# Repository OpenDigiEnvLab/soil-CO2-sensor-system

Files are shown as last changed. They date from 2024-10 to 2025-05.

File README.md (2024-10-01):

This repository provides supplementary information for the manuscript "**Overcoming barriers in long-term, continuous monitoring of soil CO2 flux: A low-cost sensor system**"
by Thi Thuc Nguyen, Nadav Bekin, Ariel Altman, Martin Maier, Nurit Agam, Elad Levintal

The repository includes:
1. Do-it-yourself guide to replicate CO2 sensor system: "CO2 sensor system DIY guide"
2.  Arduino codes of two versions of the system (Version 1:  CO2O2Soils_withRelay_6CO2sensors.ino and Version 2: CO2O2SoilsTypeB_blues_6CO2Sensors_Teros12_Serial.ino)
3.  STL file "sensor box 3" is for 3D printing frames for SCD30 sensor coating.

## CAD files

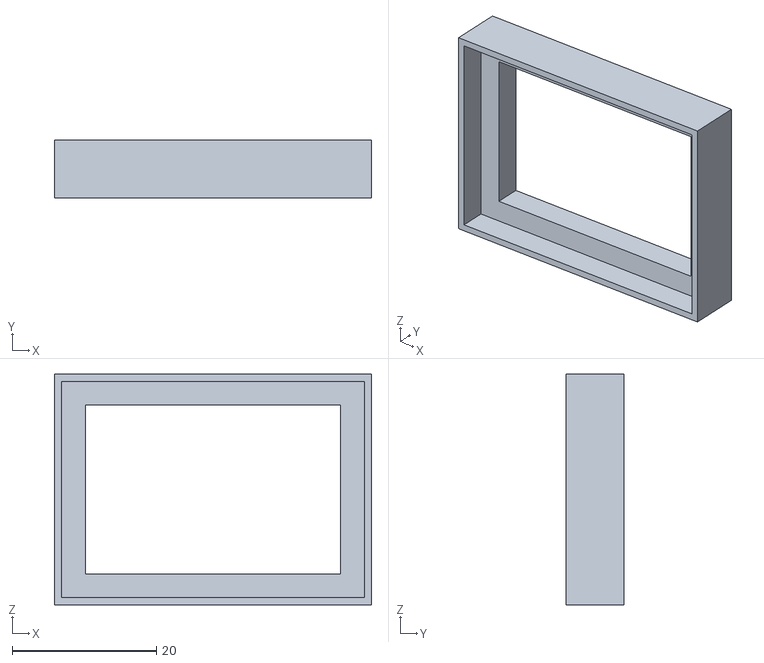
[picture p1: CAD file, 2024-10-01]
sensor box 3.STL
44.0 x 8.00 x 32.0

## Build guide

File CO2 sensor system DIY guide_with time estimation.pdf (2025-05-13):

Overcoming barriers in long-term, continuous monitoring of soil CO2 flux:

A low-cost sensor system

Thi Thuc Nguyen, Nadav Bekin, Ariel Altman, Martin Maier, Nurit Agam, Elad Levintal

This is a do-it-yourself guide for building a low-cost sensor system. Each system comprises a control unit and a sensing unit. There are two versions available, with the primary difference being that a modem and a Teros 12 moisture sensor are included in version 2. Arduino codes for both versions are available on our GitHub page.

Version 1: https://github.com/OpenDigiEnvLab/soil--sensor-system/blob/main/O2Soils_withRelay_6sensors.ino (https://github.com/OpenDigiEnvLab/soil--sensor-system/blob/main/O2Soils_withRelay_6sensors.ino)

Version 2: https://github.com/OpenDigiEnvLab/soil--sensor-system/blob/main/O2SoilsTypeB_blues_6Sensors_Teros12_Serial.ino (https://github.com/OpenDigiEnvLab/soil--sensor-system/blob/main/O2SoilsTypeB_blues_6Sensors_Teros12_Serial.ino)

The schematic designs of two versions are illustrated in the picture below:

Version 1:

Version 2:

Protocol

### 1. Control unit

To replicate the control unit of version 1, prepare the components as listed in Table 1, and follow procedure (1).

To replicate the control unit of version 2, prepare the components as listed in Table 2, and follow procedure (2).

### 2. Sensing unit

The procedure to prepare SCD30 sensors and microclimate sensor are same for both versions.

There is only one additional step to Version 2 as Teros 12 moisture sensor is included in the system.

The preparation of the sensing unit mainly involves waterproof shielding of SCD30 sensors for underground soil measurements and wiring SCD30 sensors for the connection to the control unit.

There are two designs of the waterproof shield:

- Thin coating design (TC design): using PTFE membrane and epoxy (or only PTFE membranes)
- 50 ml Falcon tube design (FT design): using a 50 ml Falcon tube.

To replicate the TC design, follow procedure (3).

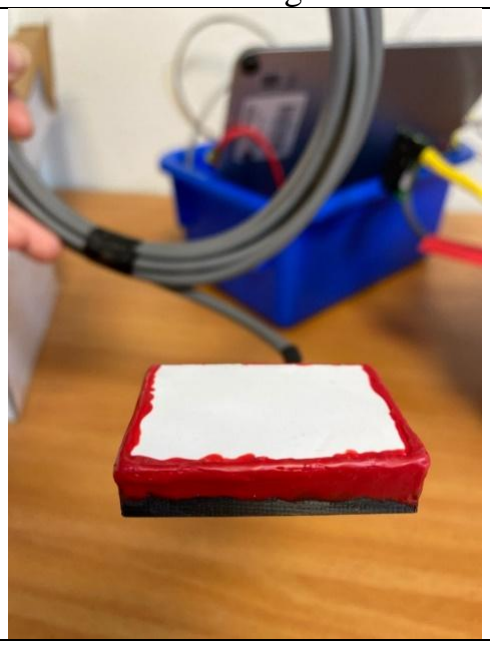
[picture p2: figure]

To replicate the FT design, follow procedure (4).

TC design | FT design

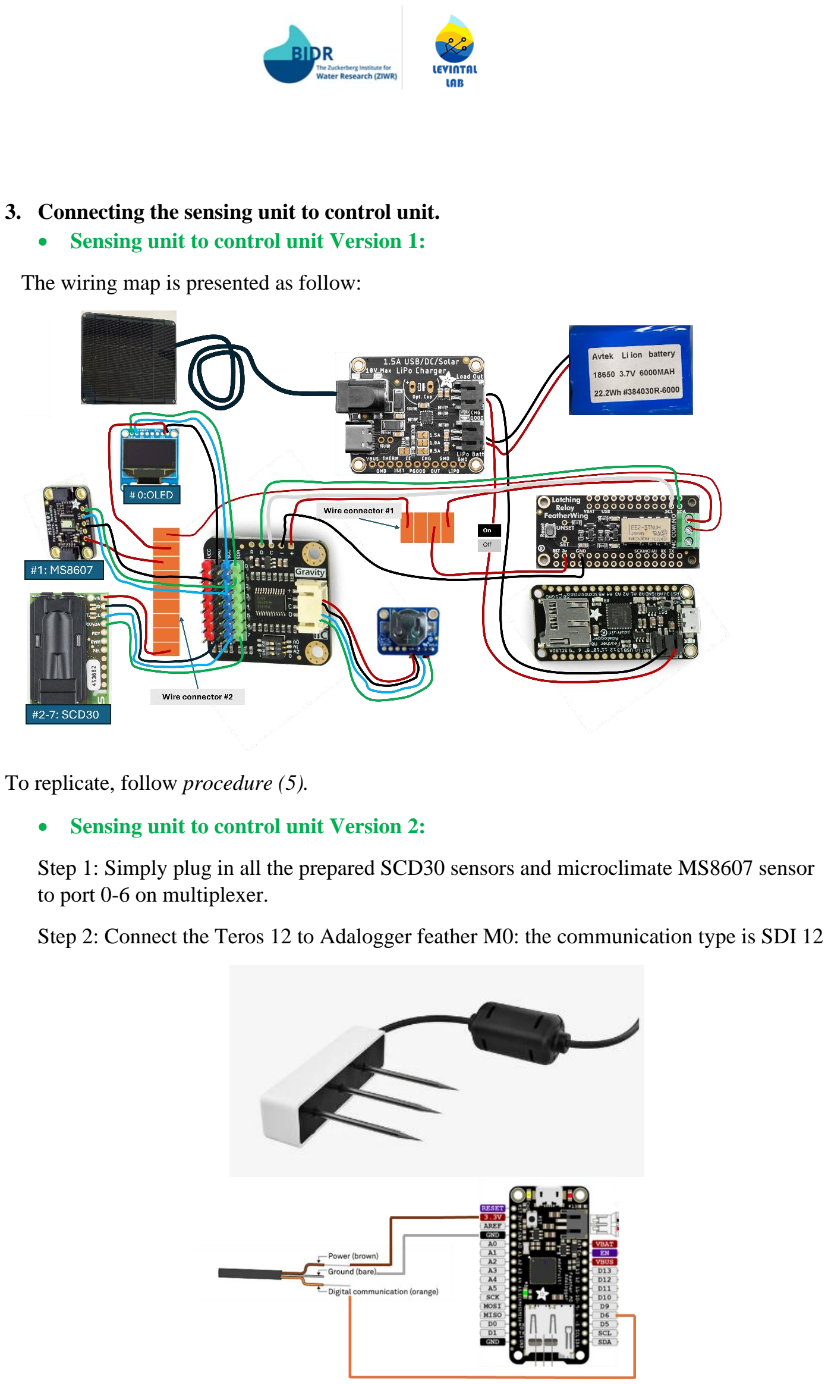
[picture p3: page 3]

3. Connecting the sensing unit to control unit.
- Sensing unit to control unit Version 1:

The wiring map is presented as follow:

To replicate, follow procedure (5).

- Sensing unit to control unit Version 2:
Step 1: Simply plug in all the prepared SCD30 sensors and microclimate MS8607 sensor to port 0-6 on multiplexer.
Step 2: Connect the Teros 12 to Adalogger feather M0: the communication type is SDI 12

4. To upload Arduino code and test sensors, follow procedure (6).

Time estimation table for building one standard system

(1 control unit + 1 sensing unit (4 thin coating sensors, 2 falcon tube sensors, 1 microclimate sensor, 1 moisture sensor))

No | Unit | Procedure | Estimated hours
1 | Control unit | Procedure (1) | ~2-5 hours
| | Procedure (2) | ~2-5 hours
2 | Sensing unit | Procedure (3) | ~24 hours (including epoxy’s drying time)
| | Procedure (4) (2 falcon tube sensors) | ~1 hour/sensor
3 | Connecting the sensing unit to the control unit | Procedure (5) | ~5 hours
4 | Upload Arduino code and test sensors | Procedure (6) | ~ 3-24 hours

Contents

Procedure (5): Connecting the sensor unit to the control unit version 1 and test the system .24

Table 1: Hardware components for system Version 1.

Component | Quantify | Cost (USD)
Sources | Comments

Hardware components for control unit – Version 1

Feather M0 Adalogger | 1 | 19.95 | Adafruit (https://www.adafruit.com/product/2796)
RTC DS3231 with CR1220 battery | 1 | 17.5 | Adafruit (https://www.adafruit.com/product/3013) | Provides accurate time for the data logger; can be purchased from other suppliers
Gravity 1-to-8 I2C Multiplexer | 1 | 6.9 | DFRobot (https://www.dfrobot.com/product-1780.html) | Enables the connections of multiple /O2 sensors to one data logger; Can be purchased from other suppliers
0.96" 128x64 OLED Graphic Display | 1 | 17.5 | Adafruit (https://www.adafruit.com/product/326) | Can be purchased from other suppliers
Latching relay FeatherWing | 1 | 7.95 | Adafruit (https://www.adafruit.com/product/2923) | For power control: programmed to turn on and turn off the system when needed
P2886A feather header kit | 1 | 0.95 | Adafruit (https://www.adafruit.com/product/2886) | To connect Feather M0 Adalogger with Latching relay FeatherWing
3.6V 6000 mAh battery | 1 | 50 | Local suppliers or online (e.g., Amazon) | To provide power for the control and sensor unit
Adafruit Universal USB / DC / Solar Lithium Ion/Polymer charger - bq24074 | 1 | 14.95 | Adafruit (https://www.adafruit.com/product/4755) | To charge the battery using the solar energy from solar panel
Medium 6V 2W Solar panel | 1 | 29 | Adafruit (https://www.adafruit.com/product/200)
SD/MicroSD memory card (8GB SDHC) | | 9.95 | Adafruit (https://www.adafruit.com/product/1294) | Can be purchased from other suppliers

Hardware components for sensing unit – Version 1 + 2

SCD30 sensor (0-10,000ppm, I2C) | 6 | 6 ×61.79 | Digikey (https://www.digikey.com/en/products/detail/sensirion-ag/SCD30/8445334) | + 4 sensors with thin coating and 2 sensors with falcon tube + Can be purchased from other suppliers
STEMMA QT MS8607 humidity temperature pressure sensor | 1 | 14.95 | Adafruit (https://www.adafruit.com/product/4716) | To measure atmospheric humidity, temperature, and pressure
50ml Falcon tube (https://www.fishersci.com/shop/products/falcon-50ml-conical-centrifuge-tubes-2/p-193321) | 2 | 1 | Local suppliers or online (e.g., Amazon) | To use for waterproofing SCD30 sensors
PTEE membrane 1/16” x 6” x 6” GR Sheets | 1 | 37.97 | McMaster (https://www.mcmaster.com/ptfe/ultra-chemical-resistant-compressible-ptfe-gasket-material-7/thickness~1-16/) | To use in the waterproofing design, allowing exchange of between sensors and the environment
Cables, wires, and general equipment: + 7 × 4-wire cable 3m (6 for SCD30 sensors and 1 for MS8607 sensor) | | ~30 | Local suppliers or online (e.g., Amazon)

+ Wires in colors white, green, red, black + 8 × 4-pin cables with Female Dupont connectors (https://www.amazon.de/-/en/Pin-Dupont-Cable-Female-Connector/dp/B01B360810) + 3 × JST PH 2pin cable-male connector (https://www.adafruit.com/product/3814) + 1× 4pin PH2.0 cable-male connector (https://www.dfrobot.com/product-2554.html) + 2 lever wire connectors + on/off switch + shrinking sleeves different sizes

Epoxy | 500 grams | 10 | Local suppliers or online (e.g., Amazon) | To use for waterproofing SCD30 sensors
Plasti Dip | 1 bottle | 10 | Local suppliers or online (e.g., Amazon) | To use for waterproofing SCD30 sensors
3D printed frame | 4 | 10 | Locally produced | To print the 3D frame for SCD30 sensor, Upload the sensor box 3.STL file (https://github.com/OpenDigiEnvLab/soil-CO2-sensor-system/blob/main/sensor%20box%203.STL) to a 3D printer and print a frame for each SCD30 sensor. We used Prusa i3 MK3S 3d printer (https://www.prusa3d.com/product/original-prusa-i3-mk3s-3d-printer-3/) using black PETG as the printing material.
Teros 12 | 1 | 450 | METER (https://metergroup.com/products/teros-12/) | Teros 12 is included in Version 2 to measure soil moisture simultaneously.

Table 2: Hardware components for system Version 2.

Component | Quantify | Cost (USD)
Sources | Comments

Hardware components for control unit – Version 2

Feather M0 Adalogger | 1 | 19.95 | Adafruit (https://www.adafruit.com/product/2796)
DS3231 Precision RTC FeatherWing with CR1220 battery | 1 | 13.95 | Adafruit (https://www.adafruit.com/product/3028) | Provides accurate time for the data logger; can be purchased from other suppliers
Notecarrier_F V1.3 | 1 | 25 | Blues (https://shop.blues.com/products/notecarrier-f)
Notecard cellular WB AN500 | 1 | 59 | Blues (https://shop.blues.com/products/notecard)
Gravity 1-to-8 I2C Multiplexer | 1 | 6.9 | DFRobot (https://www.dfrobot.com/product-1780.html) | Enables the connections of multiple /O2 sensors to one data logger; Can be purchased from other suppliers
P2886A feather header kit | 1 | 0.95 | Adafruit (https://www.adafruit.com/product/2886) | To connect Feather M0 Adalogger with RTC FeatherWing
3.6V 6000 mAh battery | 1 | 50 | Local suppliers or online (e.g., Amazon) | To provide power for the control and sensor unit
Medium 6V 2W Solar panel | 1 | 29 | Adafruit (https://www.adafruit.com/product/200)
SD/MicroSD memory card (8GB SDHC) | | 9.95 | Adafruit (https://www.adafruit.com/product/1294) | Can be purchased from other suppliers

Hardware components for sensing unit Version 2 is same as Version 1, with the only difference is the addition of Teros 12 in Version 2 (see Table 1)

## Procedure (1): Control unit Version 1

Step 1: prepare Adalogger.
- Solder the Adalogger to the header 2886 kit.
Step 2: prepare the latching relay Adafruit.

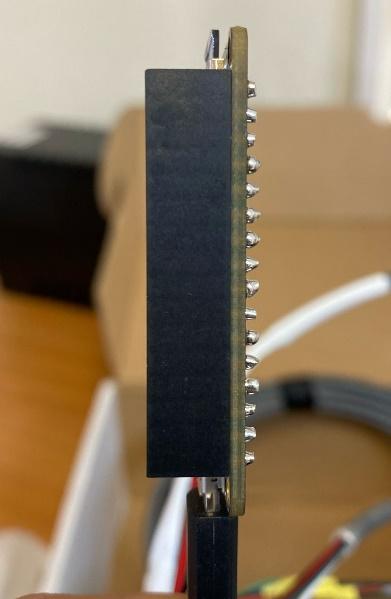
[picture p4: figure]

- The latching relay Adafruit has two pieces, solder 'the small latching piece' (1) to the main part of the relay.
- Solder latching relay Adafruit to male header pins (2). The male header pins and the header 2886 are compatible, creating the communication between the Adalogger and the latching relay Adafruit.

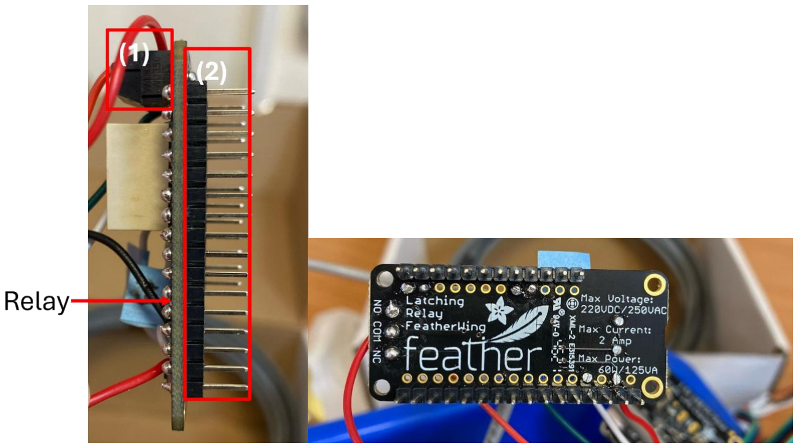
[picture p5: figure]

- Solder 2 wires 3-4 cm long connecting: Port 'set' to port #13
Port 'unset' to port #12
And label them
- Connect 2 red wires 13 cm long to two ports in 'the small latching piece' of the relay.

- Solder 13cm wires in green, white, red, black to following ports: Green wire to SDA port
White wire to SCL port
Red wire to 3V port
Black wire to GND port
These wires will be connected to other parts of the control unit.

The black piece connected
with red wires

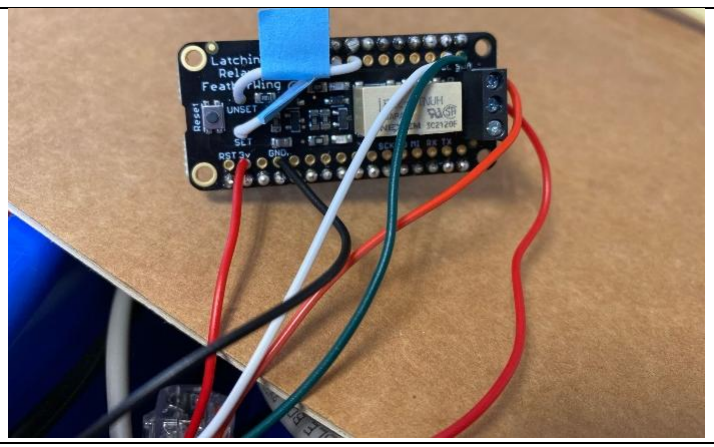
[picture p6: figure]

Latching relay Adafruit after wire soldering

Step 3: preparing the DFR 0576 multiplexer.
- Solder 15cm wires in green, white, red, black to following ports of the multiplexer:
Green wire to SDA port
White wire to SCL port
Red wire to 3V port
Black wire to GND port
Step 4: preparing the real-time clock.
- Solder the DS3231 RTC to a 15cm long 4-pin cable (green, blue, red, black) with a 4pin PH2.0 male header (that compatible to a female port of the multiplexer) Green wire to SDA port

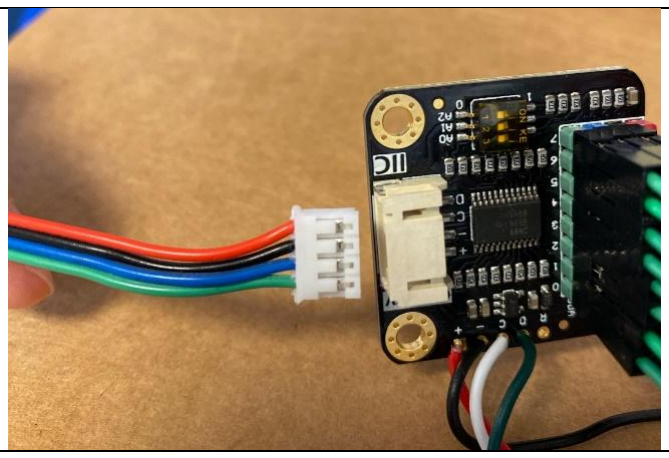
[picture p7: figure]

Blue wire to SCL port
Red wire to 3V port
Black wire to GND port
- Insert CR1220 battery into the RTC.

The DS3231 RTC with battery soldered to a 4pin cable

4pin PH2.0 male header connects the RTC to the multiplex

Step 5: preparing 128x64 OLED (Adafruit 326).
- Solder 13 cm wires in green, white, red, black to the following ports of the OLED: Green wire to data port
White wire to Clk port
Red wire to Vin port
Black wire to GND port
- Solder these wires with wires of a Dupont connector: Green wire to Green wire
White wire to Blue wire
Red wire to Red wire
Black wire to Black wire
- Protect exposed wires with shrinking sleeves.

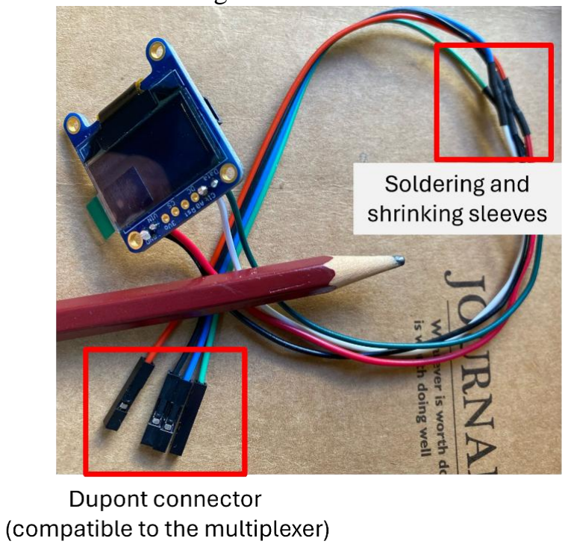
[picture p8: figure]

Step 6: Preparing battery solar panel
- Extend the cable of the solar panel:
Cut the red cable and expose the red and black wires inside.
Solder the red and black wires with red and black wires of an extended cable. *Please note that the solar panel will be outside in the field conditions, use extra shrinking sleeves and tape to protect the soldered connection.

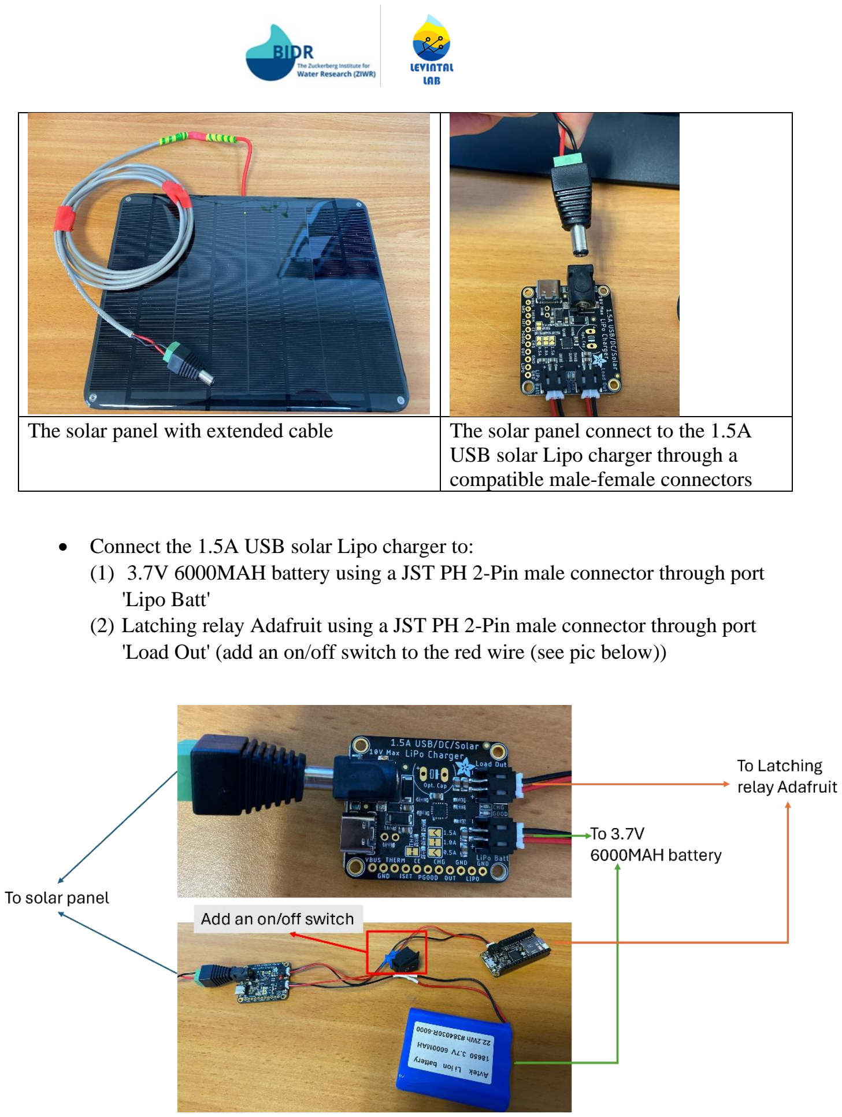
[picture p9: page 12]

The solar panel with extended cable | The solar panel connect to the 1.5A USB solar Lipo charger through a compatible male-female connectors
- Connect the 1.5A USB solar Lipo charger to:
(1) 3.7V 6000MAH battery using a JST PH 2-Pin male connector through port 'Lipo Batt'
(2) Latching relay Adafruit using a JST PH 2-Pin male connector through port 'Load Out' (add an on/off switch to the red wire (see pic below))

## Procedure (2): Control unit Version 2

Step 1: Set up Blues modem by resembling Blues Notecard + Notecarrier + Antenna

For details, please refer to Blues website (https://dev.blues.io/quickstart/notecard-quickstart/notecard-and-notecarrier-f/)

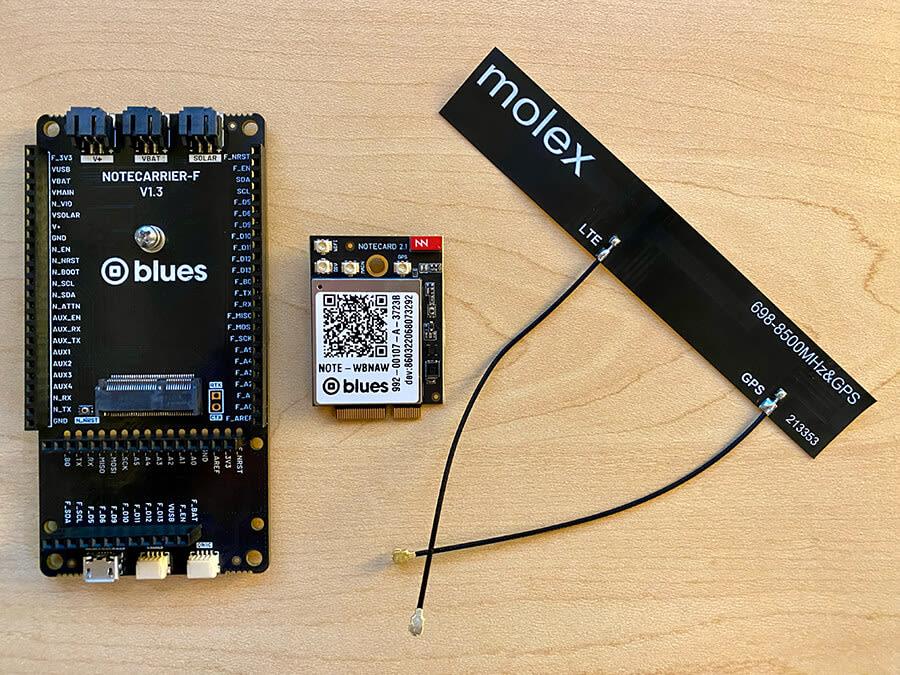
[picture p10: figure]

Step 2: Stack Adafruit feather M0 + RTC FeatherWing + Blues modem
RTC FeatherWing | Adafruit feather M0 | Blues modem

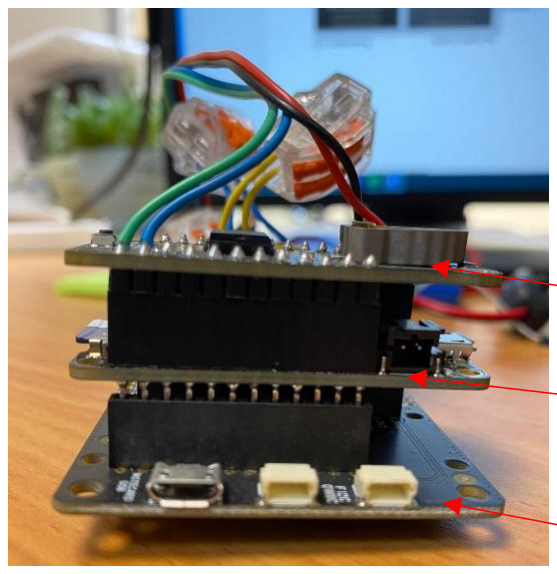
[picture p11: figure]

Soldering is needed to secure the header kit to Adalogger Feather M0 and RTC FeatherWing.

Step 3: Communicate Adalogger + Blues modem

Blues modem

Adalogger

RTC FeatherWing

- The communication between Blues modem and Adalogger can be I2C or Serial (Serial is suitable when there are a lot of sensors with long cables). Only for Serial communication, these following ports need to be connected.

On the Blues notecarrier:

Connect F_TX → N_RX (with F stands for Feather and N stands for Notecard)

Connect F_RX → N_TX

- For power saving, Blues modem can turn Adalogger on and off at desired interval. For this function, connect F_EN → ATTN
- Put switches at the back of the Notecarrier as follows:

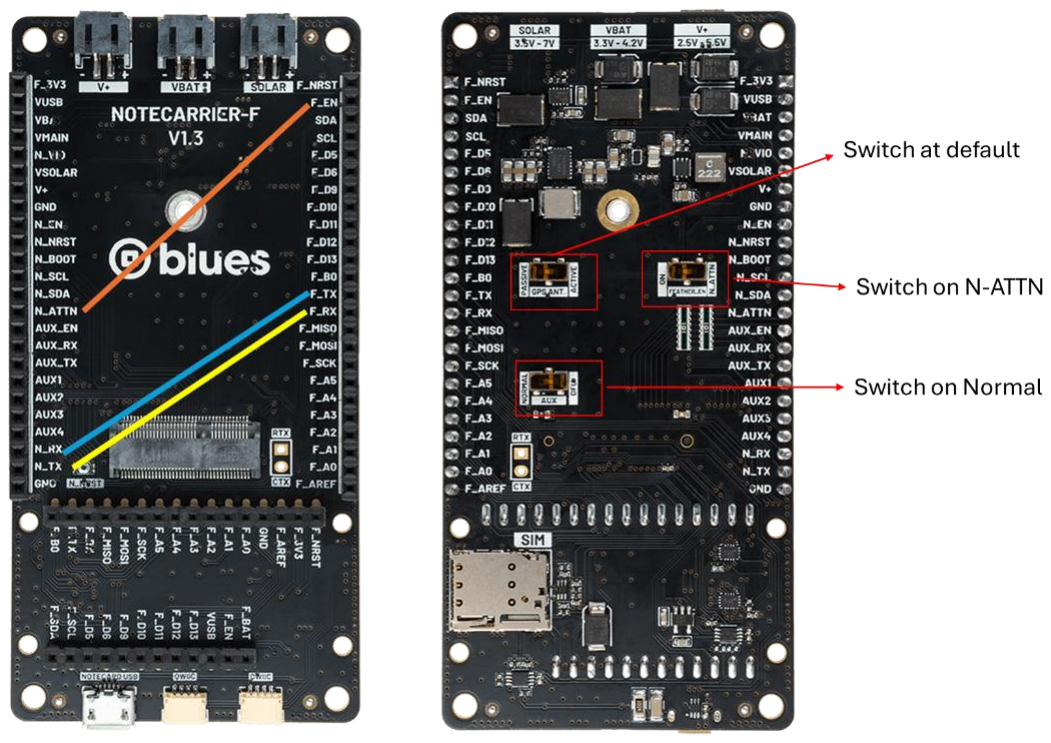
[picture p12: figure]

Step 4: Connecting the control unit to the sensor unit using a multiplexer

Plug-in the Dupont connector to the matching build-in port on multiplexer

Connect multiplexer to Adalogger feather M0 using a ST PH 4-Pin male connector:

- Solder the black wire to GND
- Solder the red wire to 3V
- Solder the blue wire to SCL
- Solder the green wire to SDA

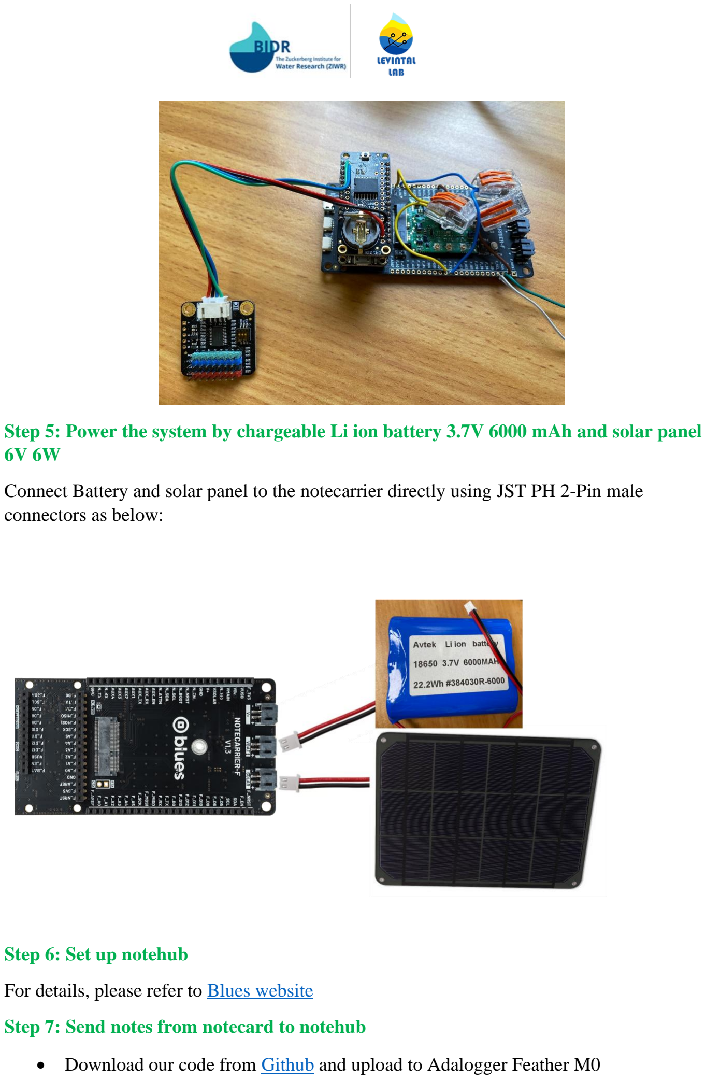
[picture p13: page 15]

Step 5: Power the system by chargeable Li ion battery 3.7V 6000 mAh and solar panel 6V 6W

Connect Battery and solar panel to the notecarrier directly using JST PH 2-Pin male connectors as below:

Step 6: Set up notehub

For details, please refer to Blues website (https://dev.blues.io/quickstart/notecard-quickstart/notecard-and-notecarrier-f/#set-up-notehub)

Step 7: Send notes from notecard to notehub
- Download our code from Github (https://github.com/OpenDigiEnvLab/soil-CO2-sensor-system) and upload to Adalogger Feather M0

- Go to https://notehub.io/projects and see in your project if your device is connected. Below is an example of one device with dev:860264050706622 is connected.

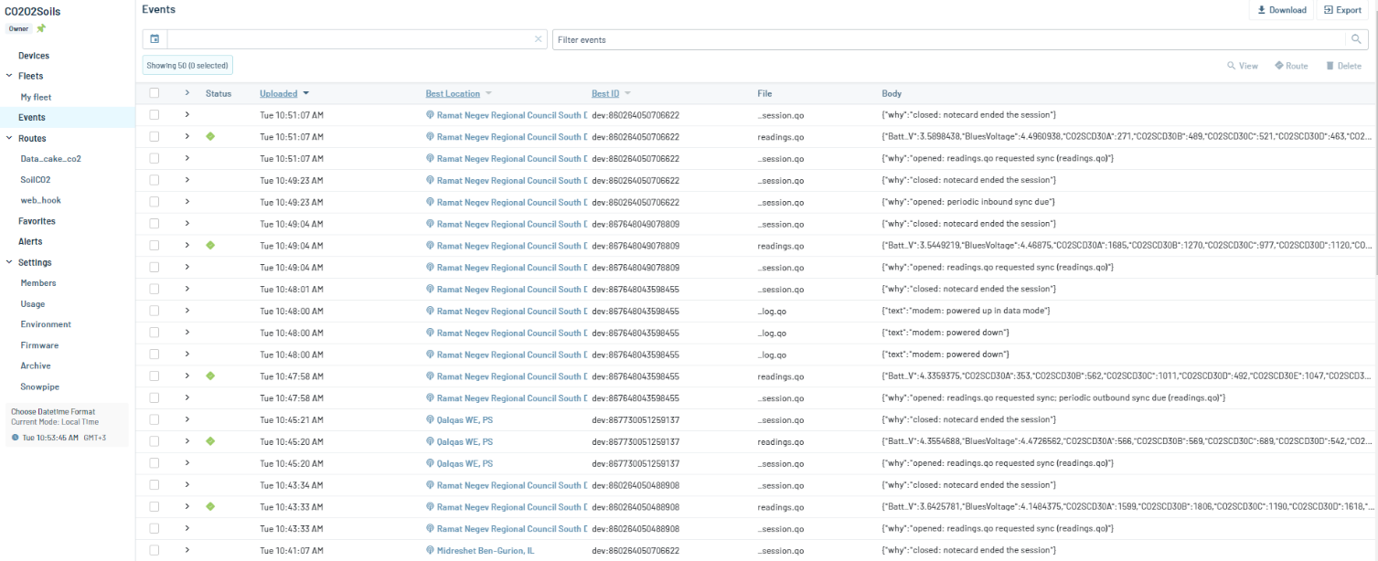
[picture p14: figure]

## Procedure (3): Thin coating design for waterproofing SCD30 sensor

To follow, notice that we address each side of the SCD30 sensor as follow:

Epoxy-filled side | Sensor-port side
Step 1: Connect male header pins to SCD30 sensor.
- Cut and insert 4 male 90° header pins (https://www.mouser.co.il/ProductDetail/TE-Connectivity/3-826631-6?qs=6Tj7fpyCzVrWp9TSRmZtQw%3D%3D) into VIN, GND, SCL and SDA ports.
- Level the pin head on the sensor-port side to avoid potential damages of the filter from the protruded headers (Tips: put the sensor-port side on a flat surface and push down the pins’ black plastic dividers using a flat-head screwdriver, see pics)

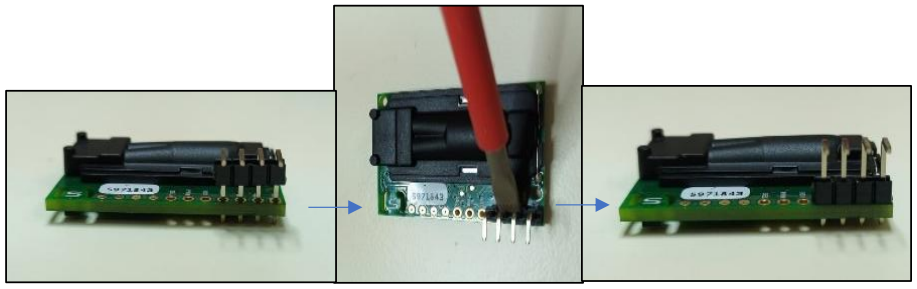
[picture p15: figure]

Step 2: Connecting SCD30 sensor with an extended cable through the male headers.
- Cut a 3m-long, 4-wire cable, expose 5cm of the cable insulators at both ends, and then expose 3-4 mm of the 4 wires’ insulators, coat wire tips with tin.

One end will be used to connect the sensor to the control unit:

- Solder 4 wires from this end to Dupont connectors (compatible to plug in the multiplexer later on)

At the other end:

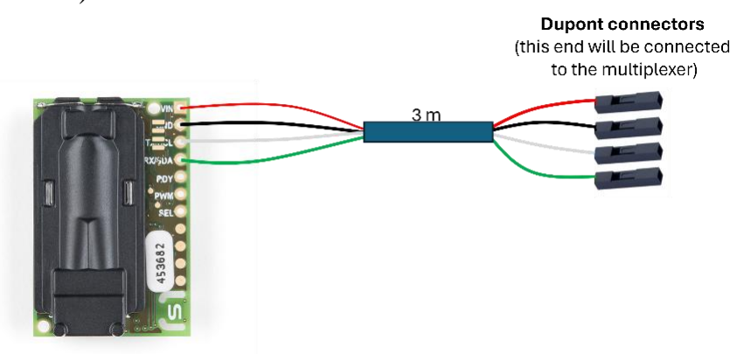
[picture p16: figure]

- Put a large shrinking sleeve (that fits over the cable) and 4 small shrinking sleeves over each of the 4 wires.
* Make sure that the length of the large sleeve fits from the wires’ edge and ~1cm over the cable insulation, while the small sleeves’ fits over the wires’ insulation and ~3mm more (to fit over the 90° header pins after soldering).
- Solder the wires to the 90° header pin:
Red wire to ‘VIN’ port
Black wire to 'GND' port
Blue to 'SCL' port
Green wire to 'SDA' port.

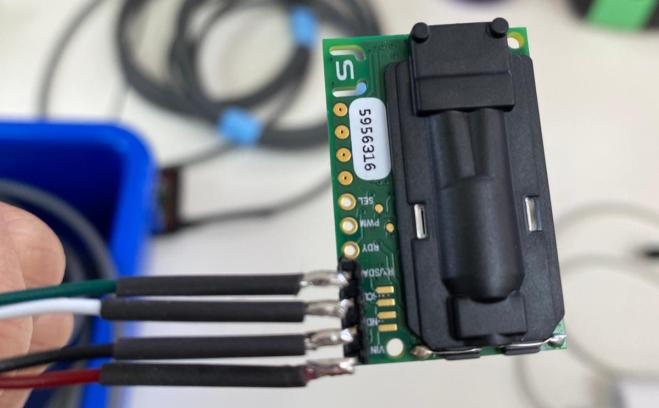
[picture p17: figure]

- Thread each of the shrinking sleeves as far down the 90° header pins as possible and shrink them using a blower, then put the large sleeve over the cable insulation and the pins and shrink it in the same way.
- Take the other end of the cable and expose ~6cm of the cable insulation, then ~3mm of each of the 4 wires’ insulation and coat the exposed wires with tin.
- Check the sensor using procedure (6).
Step 3: Plasti Dip (https://plastidip.com/product/plastidip/) sealing
- The purpose of this Plasti Dip (https://plastidip.com/product/plastidip/) sealing step is to avoid epoxy block , T- RH ports and damaging the sensor.
- Fit the SCD30 sensor into the 3D printed frame.
- Identify all the openings on the epoxy-filled side that need to be sealed (marked in red).

- Stabilize the sensor-frame unit with the epoxy-filled side face up and use a 10cc syringe and a18G needle (1.2x38mm) to slowly and carefully apply Plasti Dip on all the red marked (including the gap between the sensor and the frame, the unused round pin ports, the ports (topside only!), 2 ‘L’ shape openings on both sides of the ‘S’ logo and the 2 holes for griping with spacers).
- After drying (~30 mins) make sure no bubbles, shafts or crevasses formed due to the shrinking and drying of the Plasti Dip. If you notice any – seal individually again with Plasti Dip, wait for drying and make sure there are no holes again till it’s sealed.
- Turn the sensor-frame unit with the sensor-port face up, and seal the openings on this side as well (See picture below).

- Check the sensor using procedure (6).
Step 4: Epoxy sealing

This step is optional. Instead of epoxy sealing, users can use two PTFE membranes on two sides of the SCD30 sensors (repeat Step 5 on both sides of the sensor)

- Prepare your working environment: put paper towels on a flat, steady surface, stabilize your sensor-frame units in such a way that they’re leveled (so epoxy could be filled to the top of the frame without spilling), use latex gloves while working with epoxy.
- Prepare the mixture: We used a local manufacturer - Polymer|G (https://www.polymer-g.com/) , mixing the two components EPC 1455: EP 169 in a ratio of 1:5 (can be replaced with any locally available products).
- Weigh 2 gr of EPC 1455 and 10 gr of EP 169 and mix well for at least 2 mins (total 12 gr epoxy should be more than enough for 2 sensor-frame units – working with smaller amount is not recommended).
- Level the sensor-frame unit with the epoxy-filled side face up, pour the liquid epoxy into the frame, on top of the sensor till it reaches the top of the frame without spilling or touching anything else (e.g., your units’ stabilizing setup).

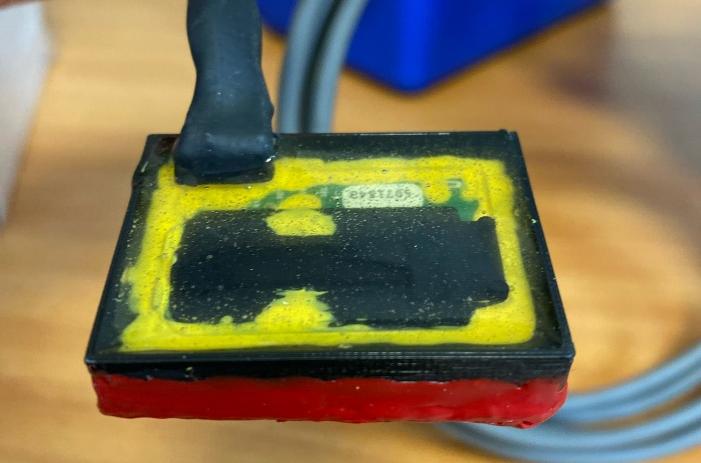
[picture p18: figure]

- Wait for it to dry between ½ day and 1.5 days (depending on the environment in which it dries).
- Check the sensor using procedure (6).
- PTEE membrane will be glued to the sensor-port side of the sensor.
- PTEE membrane used in this study is 1/16” x 6” x 6” GR Sheets from McMaster (https://www.mcmaster.com/ptfe/ultra-chemical-resistant-compressible-ptfe-gasket-material-7/) (95665K92 - 1/16'' thick), which should be cut to match the size of the 3D frame.
- Carefully apply superglue around the frame edges (see pic) and put the cut PTFE on it.
- Apply some pressure by putting a small weight on the PTEE menbrane (see pic), then wait ~20 mins for drying.

PlastiDip around the edges between the PTEE membrane and the frame.

- Check the sensor using procedure (6).

## Procedure (4): Falcon tube design for waterproofing SCD30 sensor

Step 1: Preparing the Falcon tube.
- Measure and cut the falcon tube to have a part 6-6.5 cm long from the cap.
- Drill a hole big enough to pull the 4-wire cable through.
- At the cut end of the tube, cover it with PTEE membrane using superglue (the same membrane as described in the TC design) and seal the edges with PlastiDip (repeat 2 times if needed).
Step 2: Preparing SCD30 sensor.

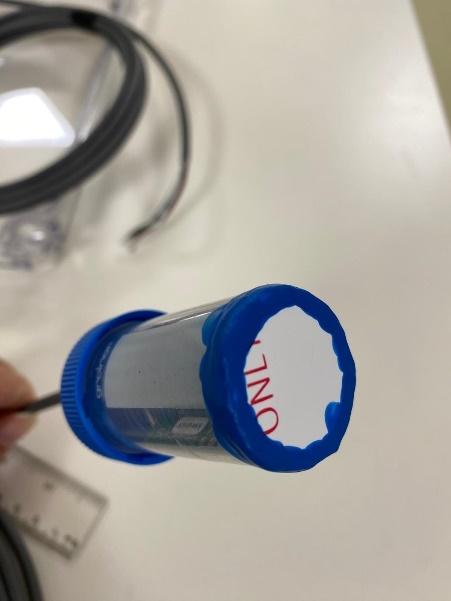
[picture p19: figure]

- Use a 4-wire cable 3 m long, exposed 10 cm of the cable insulator at both ends, then exposed 3-4 mm of the wire insulator, coated exposed wire tips with tin.
- First end of the 3m cable: Solder 4 small wires in colors: green, white, red, black to the corresponding ports on the sensor (SCD30) in order:
Green wire to SDA port
White wire to SCL port
Red wire to VIN port
Black wire to GND port
- Pull the cable through the hole on the Falcon tube's cap so that at the end the SCD30 sensor will be inside the tube.

- Second end of the 3m cable: Solder 4 small wires in colors: green, white, red, black to 4-pin cable with black female Dupont connectors (see pic below):

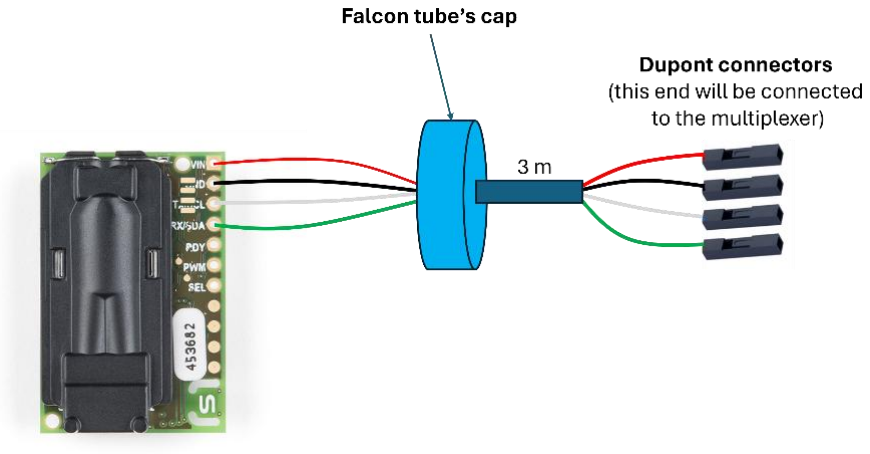
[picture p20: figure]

- Seal the edges between the 4-wire cable and the hole with PlastiDip (repeat 2 times if needed).
- Put the sensor inside the tube, close the cap and complete waterproofing SCD30 sensor with Falcon tube design.

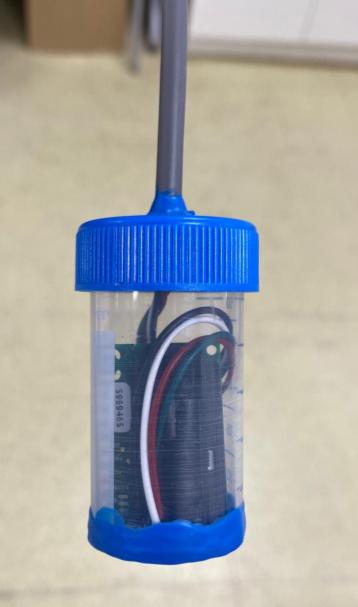
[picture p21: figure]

## Procedure (5): Connecting the sensor unit to the control unit version 1 and test the system

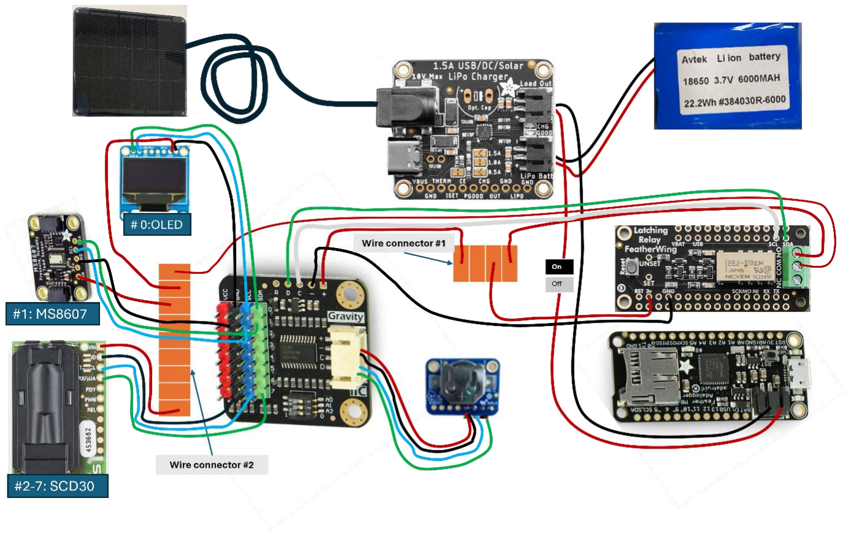
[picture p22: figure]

Step 1: Connect the latching relay to the multiplexer.
- Solder the white wire from the SCL port of the relay to port C in the multiplexer.
- Solder the green wire from the SCD port of the relay to port D in the multiplexer.
- Solder the black wire from the GND port of the relay to port ' – ' in the multiplexer.
Step 2: Battery unit
- Connect the solar panel to the 1.5A USB solar Lipo charger.
- Connect the Li-ion battery to the 1.5A USB solar Lipo charger at "Lipo Batt" port.
- Connect the latching relay-Adalogger unit using the read-made female port on the Adalogger to the 1.5A USB solar Lipo charger at "Load out" port.
Step 3: The multiplexer
- Connect the RTC to the multiplexer using a ready-made female port (see pic)
- Connect the green, blue, black wires of the OLED to port#0 of the multiplexer.
- Connect the green, blue, black wires of the MS8607 sensor to port#1 of the multiplexer.
- Connect the green, blue, black wires of the SCD30 to port #2-7 of the multiplexer.
Step 4: connecting red wires to control power through the latching relay.

Wire connector #1 contains:

- One of the red wires from the 'small latching piece' of the relay.
- Red wire from 3v port of the latching relay.

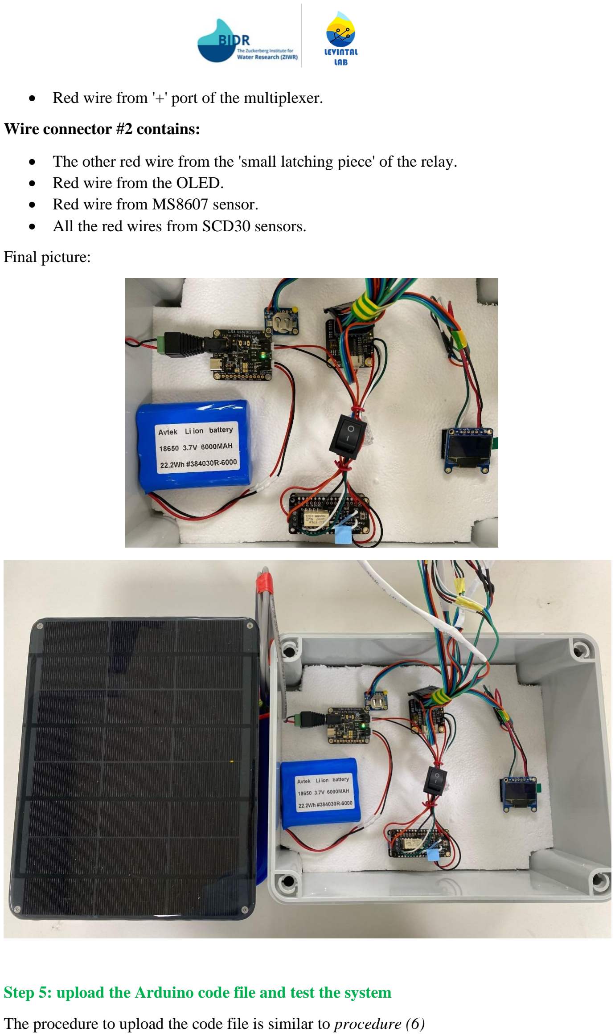
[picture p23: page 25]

- Red wire from '+' port of the multiplexer.

Wire connector #2 contains:

- The other red wire from the 'small latching piece' of the relay.
- Red wire from the OLED.
- Red wire from MS8607 sensor.
- All the red wires from SCD30 sensors.

Final picture:

Step 5: upload the Arduino code file and test the system

The procedure to upload the code file is similar to procedure (6)

## Procedure (6): Embedding Arduino code and checking sensors

First Timer (internet required):

To make sure that the shielding didn’t damage the sensors you can check them before and after they’re sealed. The following stages are for new users and describe how to connect a PC to a SCD30 using Arduino IDE software to check the sensors:

- Use a logger setup to connect to the sensor, e.g., Feather M0 adalogger (https://learn.adafruit.com/adafruit-feather-m0-adalogger/overview) and a corresponding terminal block FeatherWing (https://www.adafruit.com/product/2926) with wires and connectors as needed (See pic on the right), and connect to a PC.

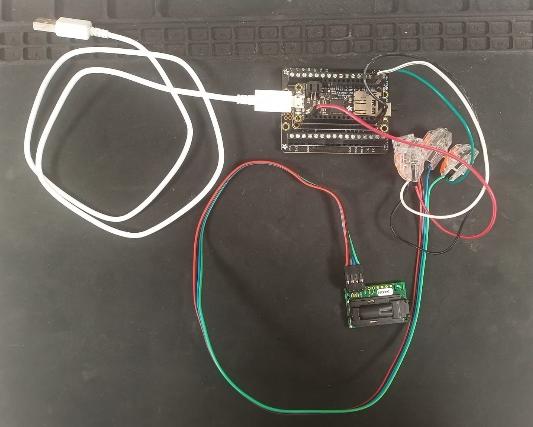
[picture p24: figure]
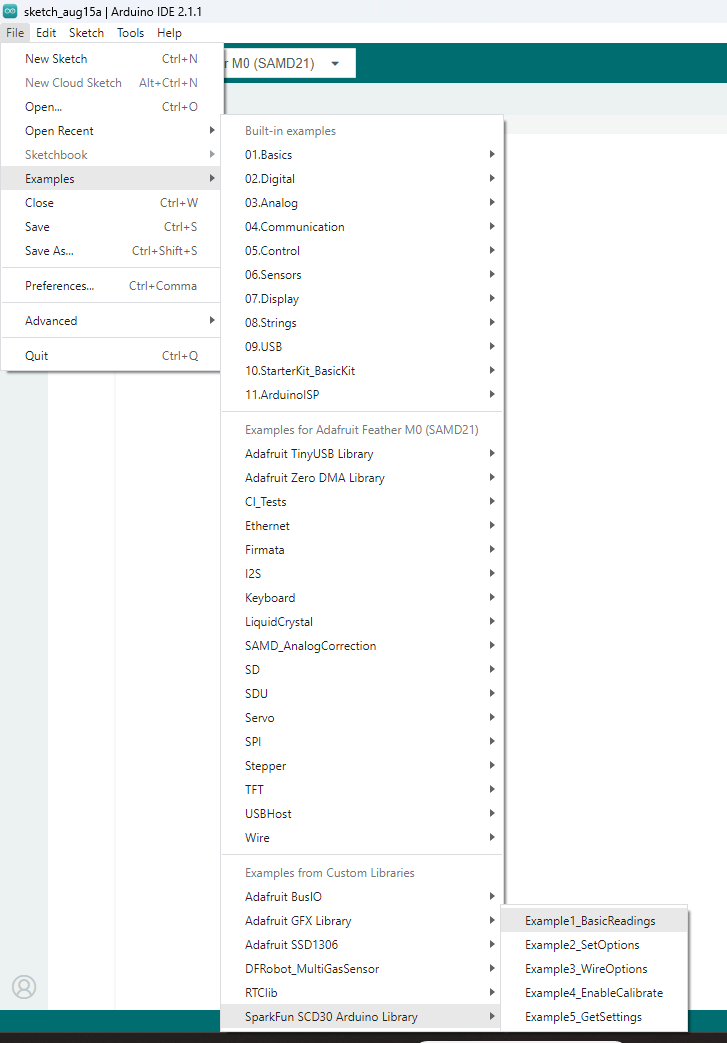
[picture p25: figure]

- On a PC open Arduino IDE.
- Select port and board.
- Install SparkFun SCD30 Arduino library. (https://www.arduino.cc/reference/en/libraries/sparkfun-scd30-arduino-library/)
- Upload SCD30 example code: File/Examples/Examples from Custom Libraries/Example1_BasicReadings.
- Press the Verify key and install any boards/libraries that you don’t yet have. Every time you install one, Verify again (compiles the code) and you’ll encounter another missing board/library (till no error pops up).

Second Timer

- Connect the SCD30 to the datalogger and the datalogger to a PC (See ‘First Timer’ section).
- Open Arduino IDE
- Send example code to datalogger by pressing the Upload key.
- Open ‘Serial Monitor’ and make sure that all values make sense (Temp, RH and ). Blow on the sensor to watch the values change accordingly.

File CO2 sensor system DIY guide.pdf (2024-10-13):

Overcoming barriers in long-term, continuous monitoring of soil CO2 flux: A low-cost sensor system

Thi Thuc Nguyen, Nadav Bekin, Ariel Altman, Martin Maier, Nurit Agam, Elad Levintal

This is a do-it-yourself guide for building a low-cost sensor system. Each system comprises a control unit and a sensing unit. The system is available in two versions: Version 1, used to produce the data presented in this paper, and Version 2, an upgrade with a modem for online data access and a Teros 12 moisture sensor. Arduino code for both versions can be accessed on our GitHub page.

Version 1: https://github.com/OpenDigiEnvLab/soil--sensor-system/blob/main/O2Soils_withRelay_6sensors.ino (https://github.com/OpenDigiEnvLab/soil--sensor-system/blob/main/O2Soils_withRelay_6sensors.ino)

Version 2: https://github.com/OpenDigiEnvLab/soil--sensor-system/blob/main/O2SoilsTypeB_blues_6Sensors_Teros12_Serial.ino (https://github.com/OpenDigiEnvLab/soil--sensor-system/blob/main/O2SoilsTypeB_blues_6Sensors_Teros12_Serial.ino)

The schematic designs of the two versions are illustrated in the picture below:

Version 1:

Version 2:

Protocol

### 1. Control unit

To replicate the control unit of version 1, prepare the components as listed in Table 1, and follow procedure (1).

To replicate the control unit of version 2, prepare the components as listed in Table 2, and follow procedure (2).

### 2. Sensing unit

The procedure to prepare SCD30 sensors and microclimate sensor are same for both versions.

There is only one additional step to Version 2, as Teros 12 moisture sensor is included in the system.

The preparation of the sensing unit mainly involves waterproof shielding SCD30 sensors for underground soil measurements and wiring SCD30 sensors for the connection to the control unit.

There are two designs of the waterproof shield:

- Thin coating design (TC design): using PTFE membrane and epoxy (or only PTFE membranes)
- 50 ml Falcon tube design (FT design): using a 50 ml Falcon tube.

To replicate the TC design, follow procedure (3).

To replicate the FT design, follow procedure (4).

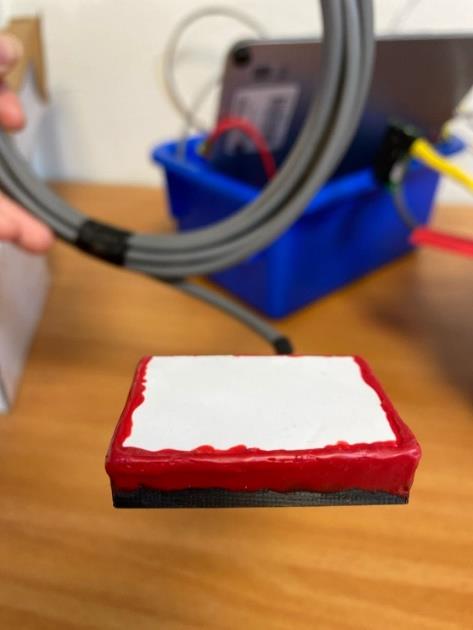
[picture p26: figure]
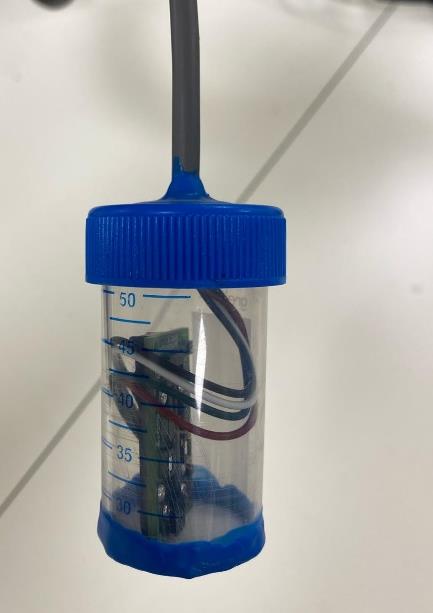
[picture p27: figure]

3. Connecting the sensing unit to the control unit.
- Sensing unit to control unit Version 1:
TC design | FT design

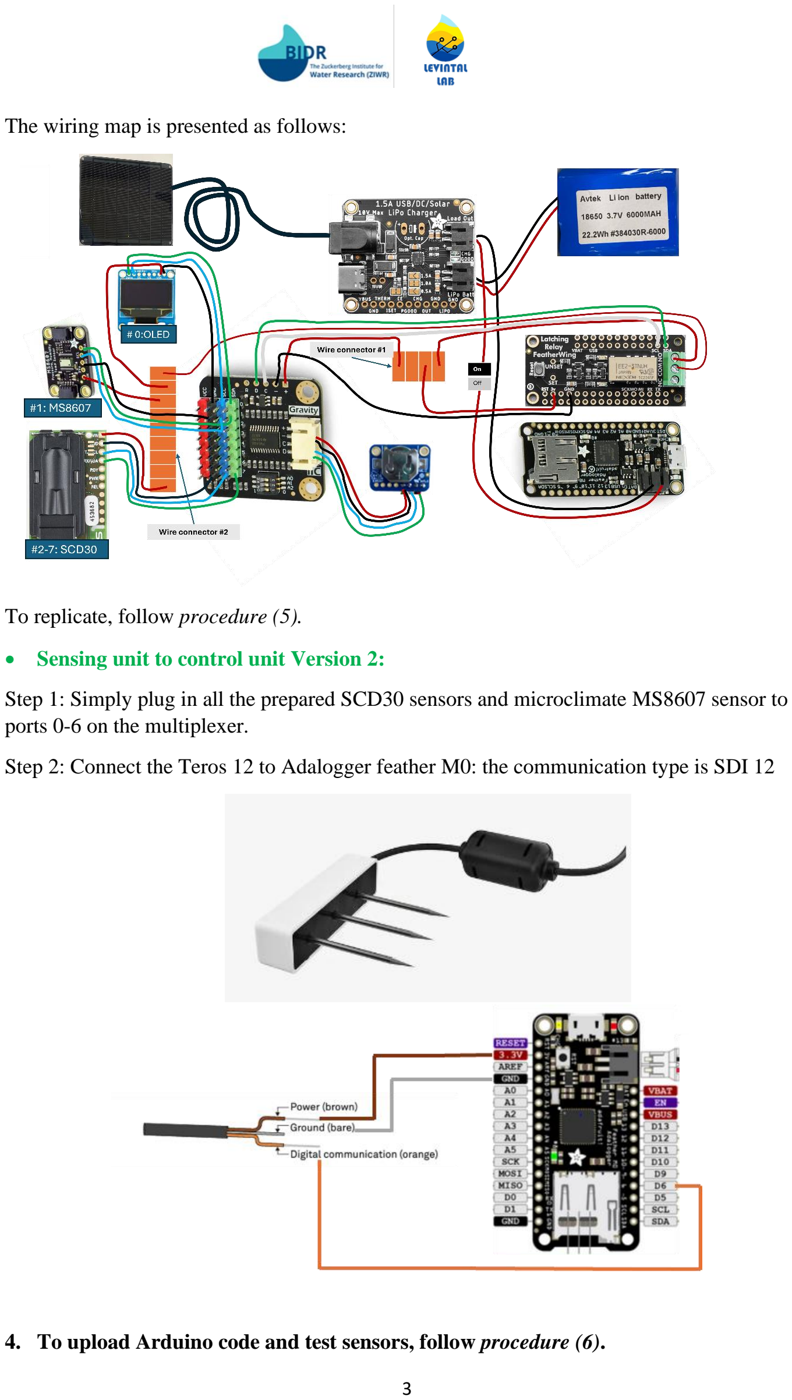
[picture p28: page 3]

The wiring map is presented as follows:

To replicate, follow procedure (5).

- Sensing unit to control unit Version 2:
Step 1: Simply plug in all the prepared SCD30 sensors and microclimate MS8607 sensor to ports 0-6 on the multiplexer.
Step 2: Connect the Teros 12 to Adalogger feather M0: the communication type is SDI 12
4. To upload Arduino code and test sensors, follow procedure (6).

Contents

Procedure (5): Connecting the sensor unit to the control unit version 1 and test the system .23

Table 1: Hardware components for system Version 1.

Component | Quantity | Cost (USD)
Sources | Comments

Hardware components for control unit – Version 1

Feather M0 Adalogger | 1 | 19.95 | Adafruit (https://www.adafruit.com/product/2796)
RTC DS3231 with CR1220 battery | 1 | 17.5 | Adafruit (https://www.adafruit.com/product/3013) | Provides accurate time for the data logger; can be purchased from other suppliers
Gravity 1-to-8 I2C Multiplexer | 1 | 6.9 | DFRobot (https://www.dfrobot.com/product-1780.html) | Enables the connections of multiple /O2 sensors to one data logger; Can be purchased from other suppliers
0.96" 128x64 OLED Graphic Display | 1 | 17.5 | Adafruit (https://www.adafruit.com/product/326) | Can be purchased from other suppliers
Latching relay FeatherWing | 1 | 7.95 | Adafruit (https://www.adafruit.com/product/2923) | For power control: programmed to turn on and turn off the system when needed
P2886A feather header kit | 1 | 0.95 | Adafruit (https://www.adafruit.com/product/2886) | To connect Feather M0 Adalogger with Latching relay FeatherWing
3.6V 6000 mAh battery | 1 | 50 | Local suppliers or online (e.g., Amazon) | To provide power for the control and sensor unit
Adafruit Universal USB / DC / Solar Lithium Ion/Polymer charger - bq24074 | 1 | 14.95 | Adafruit (https://www.adafruit.com/product/4755) | To charge the battery using the solar energy from solar panel
Medium 6V 2W Solar panel | 1 | 29 | Adafruit (https://www.adafruit.com/product/200)
SD/MicroSD memory card (8GB SDHC) | | 9.95 | Adafruit (https://www.adafruit.com/product/1294) | Can be purchased from other suppliers

Hardware components for sensing unit – Version 1 + 2

SCD30 sensor (0-10,000ppm, I2C) | 6 | 6 ×61.79 | Digikey (https://www.digikey.com/en/products/detail/sensirion-ag/SCD30/8445334) | + 4 sensors with thin coating and 2 sensors with falcon tube + Can be purchased from other suppliers
STEMMA QT MS8607 humidity temperature pressure sensor | 1 | 14.95 | Adafruit (https://www.adafruit.com/product/4716) | To measure atmospheric humidity, temperature, and pressure
50ml Falcon tube (https://www.fishersci.com/shop/products/falcon-50ml-conical-centrifuge-tubes-2/p-193321) | 2 | 1 | Local suppliers or online (e.g., Amazon) | To use for waterproofing SCD30 sensors
PTEE membrane 1/16” x 6” x 6” GR Sheets | 1 | 37.97 | McMaster (https://www.mcmaster.com/ptfe/ultra-chemical-resistant-compressible-ptfe-gasket-material-7/thickness~1-16/) | To use in the waterproofing design, allowing exchange of between sensors and the environment
Cables, wires, and general equipment: + 7 × 4-wire cable 3m (6 for SCD30 sensors | | ~30 | Local suppliers or online (e.g., Amazon)

and 1 for MS8607 sensor) + Wires in colors white, green, red, black + 8 × 4-pin cables with Female Dupont connectors (https://www.amazon.de/-/en/Pin-Dupont-Cable-Female-Connector/dp/B01B360810) + 3 × JST PH 2pin cable-male connector (https://www.adafruit.com/product/3814) + 1× 4pin PH2.0 cable-male connector (https://www.dfrobot.com/product-2554.html) + 2 lever wire connectors + on/off switch + shrinking sleeves different sizes

Epoxy | 500 grams | 10 | Local suppliers or online (e.g., Amazon) | To use for waterproofing SCD30 sensors
Plasti Dip | 1 bottle | 10 | Local suppliers or online (e.g., Amazon) | To use for waterproofing SCD30 sensors
3D printed frame | 4 | 10 | Locally produced | To print the 3D frame for SCD30 sensor, Upload the sensor box 3.STL file (https://github.com/OpenDigiEnvLab/soil-CO2-sensor-system/blob/main/sensor%20box%203.STL) to a 3D printer and print a frame for each SCD30 sensor. We used Prusa i3 MK3S 3d printer (https://www.prusa3d.com/product/original-prusa-i3-mk3s-3d-printer-3/) using black PETG as the printing material.
Teros 12 | 1 | 450 | METER (https://metergroup.com/products/teros-12/) | Teros 12 is included in Version 2 to measure soil moisture simultaneously.

Table 2: Hardware components for system Version 2.

Component | Quantity | Cost (USD)
Sources | Comments

Hardware components for control unit – Version 2

Feather M0 Adalogger | 1 | 19.95 | Adafruit (https://www.adafruit.com/product/2796)
DS3231 Precision RTC FeatherWing with CR1220 battery | 1 | 13.95 | Adafruit (https://www.adafruit.com/product/3028) | Provides accurate time for the data logger; can be purchased from other suppliers
Notecarrier_F V1.3 | 1 | 25 | Blues (https://shop.blues.com/products/notecarrier-f)
Notecard cellular WB AN500 | 1 | 59 | Blues (https://shop.blues.com/products/notecard)
Gravity 1-to-8 I2C Multiplexer | 1 | 6.9 | DFRobot (https://www.dfrobot.com/product-1780.html) | Enables the connections of multiple /O2 sensors to one data logger; Can be purchased from other suppliers
P2886A feather header kit | 1 | 0.95 | Adafruit (https://www.adafruit.com/product/2886) | To connect Feather M0 Adalogger with RTC FeatherWing
3.6V 6000 mAh battery | 1 | 50 | Local suppliers or online (e.g., Amazon) | To provide power for the control and sensor unit
Medium 6V 2W Solar panel | 1 | 29 | Adafruit (https://www.adafruit.com/product/200)
SD/MicroSD memory card (8GB SDHC) | | 9.95 | Adafruit (https://www.adafruit.com/product/1294) | Can be purchased from other suppliers

Hardware components for sensing unit Version 2 are the same as Version 1, with the only difference being the addition of Teros 12 in Version 2 (see Table 1)

## Procedure (1): Control unit Version 1

Step 1: prepare Adalogger.
- Solder the Adalogger to the header 2886 kit.
Step 2: Prepare the latching relay Adafruit.
- The latching relay Adafruit has two pieces, solder 'the small latching piece' (1) to the main part of the relay.
- Solder latching relay Adafruit to male header pins (2). The male header pins and the header 2886 are compatible, creating the communication between the Adalogger and the latching relay Adafruit.

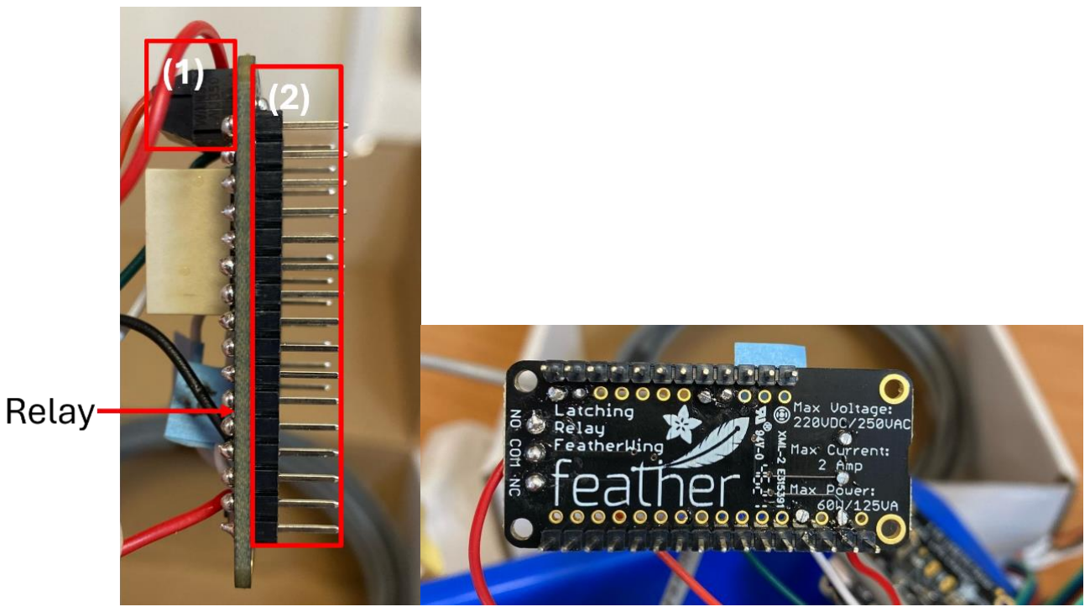
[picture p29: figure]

- Solder 2 wires 3cm long connecting: Port 'set' to port #13
Port 'unset' to port #12
And label them
- Connect 2 red wires 13 cm long to two ports in 'the small latching piece' of the relay.

- Solder 13cm wires in green, white, red, black to following ports: Green wire to SDA port
White wire to SCL port
Red wire to 3V port
Black wire to GND port
These wires will be connected to other parts of the control unit.

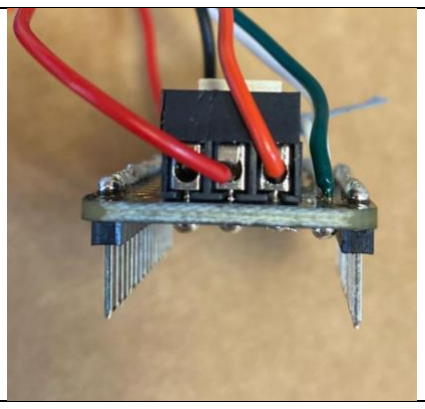
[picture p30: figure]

The black piece connected
with red wires

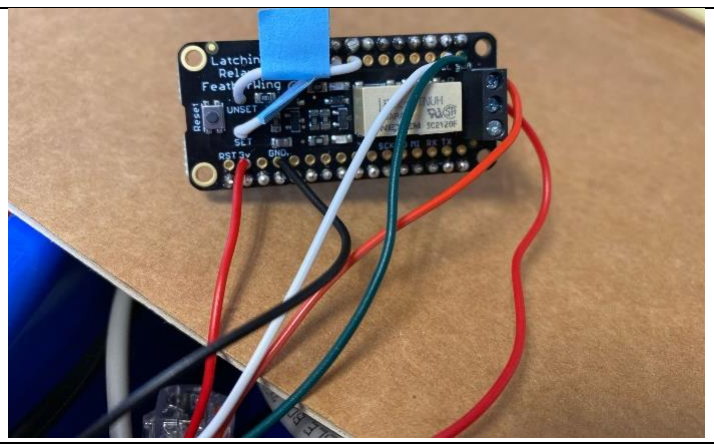
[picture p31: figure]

Latching relay Adafruit after wire soldering

Step 3: Prepare the DFR 0576 multiplexer.
- Solder 15cm wires in green, white, red, and black to the following ports of the multiplexer:
Green wire to SDA port
White wire to SCL port
Red wire to 3V port
Black wire to GND port
Step 4: Prepare the real-time clock.
- Solder the DS3231 RTC to a 15cm long 4-pin cable (green, blue, red, black) with a 4pin PH2.0 male header (that is compatible to a female port of the multiplexer) Green wire to SDA port
Blue wire to SCL port
Red wire to 3V port
Black wire to GND port
- Insert CR1220 battery into the RTC.

The DS3231 RTC with battery soldered to a 4pin cable

4pin PH2.0 male header connects the RTC to the multiplex

Step 5: Prepare 128x64 OLED (Adafruit 326).
- Solder 13 cm wires in green, white, red, and black to the following ports of the OLED:
Green wire to data port
White wire to Clk port
Red wire to Vin port
Black wire to GND port
- Solder these wires with wires of a Dupont connector: Green wire to Green wire
White wire to Blue wire
Red wire to Red wire
Black wire to Black wire
- Protect exposed wires with shrinking sleeves.

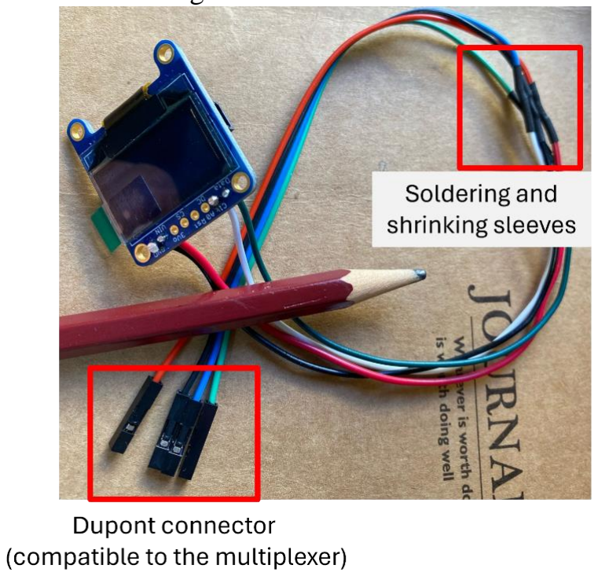
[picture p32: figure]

Step 6: Preparing battery solar panel
- Extend the cable of the solar panel: Cut the red cable and expose the red and black wires inside.
Solder the red and black wires with red and black wires of an extended cable. *Please note that the solar panel will be outside in the field conditions, use extra shrinking sleeves and tape to protect the soldered connection.

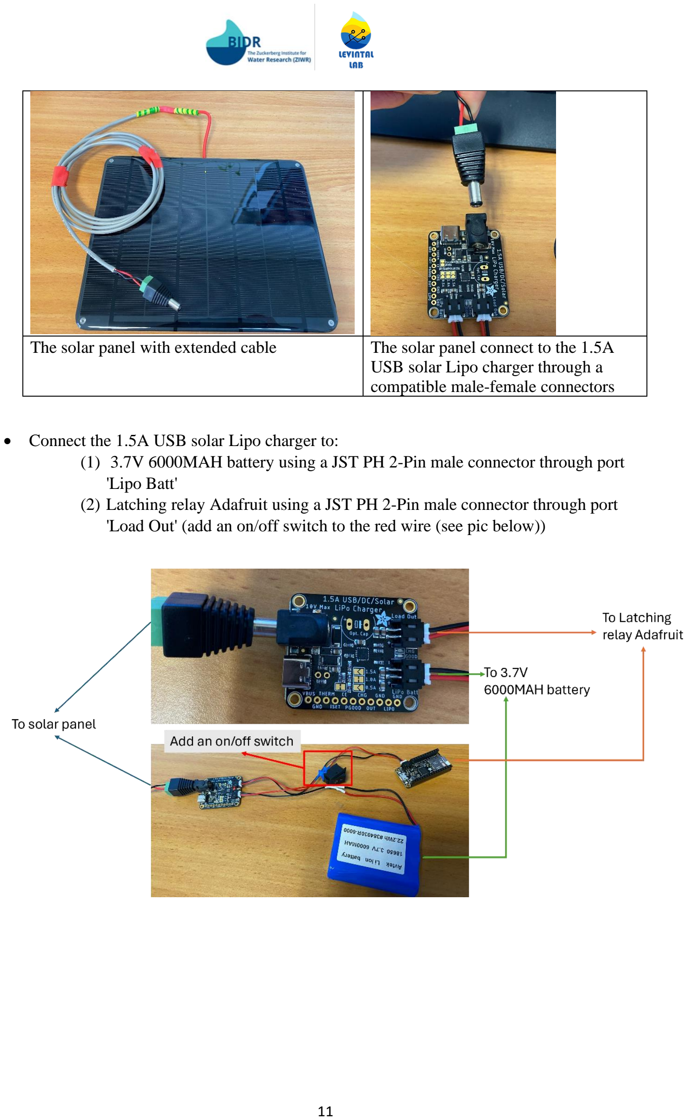
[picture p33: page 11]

The solar panel with extended cable | The solar panel connect to the 1.5A USB solar Lipo charger through a compatible male-female connectors
- Connect the 1.5A USB solar Lipo charger to:
(1) 3.7V 6000MAH battery using a JST PH 2-Pin male connector through port 'Lipo Batt'
(2) Latching relay Adafruit using a JST PH 2-Pin male connector through port 'Load Out' (add an on/off switch to the red wire (see pic below))

## Procedure (2): Control unit Version 2

Step 1: Set up Blues modem by resembling Blues Notecard + Notecarrier + Antenna

For details, please refer to Blues website (https://dev.blues.io/quickstart/notecard-quickstart/notecard-and-notecarrier-f/)

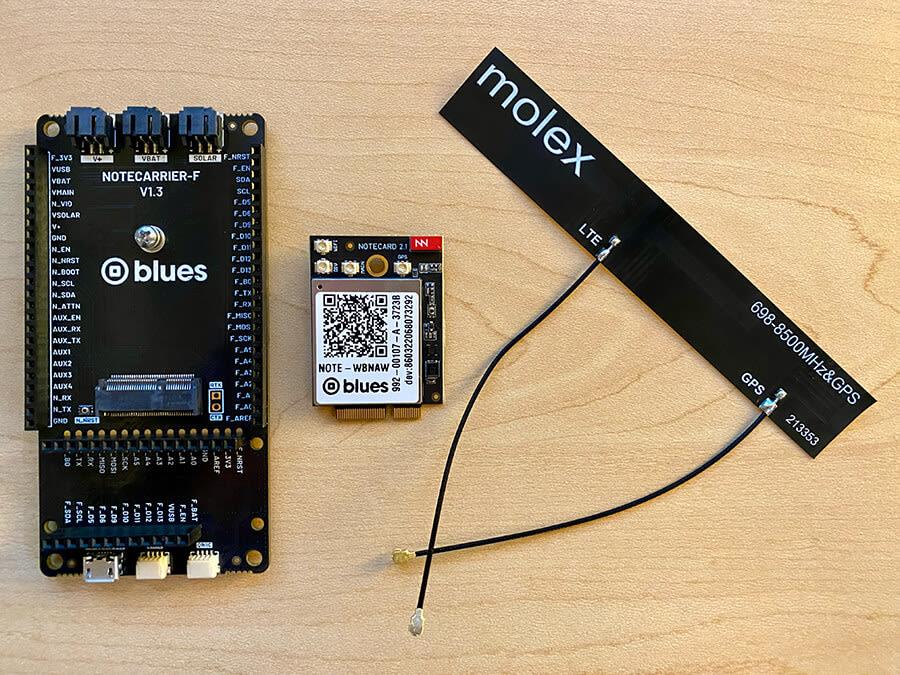
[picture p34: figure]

Step 2: Stack Adafruit feather M0 + RTC FeatherWing + Blues modem
RTC FeatherWing | Adafruit feather M0 | Blues modem

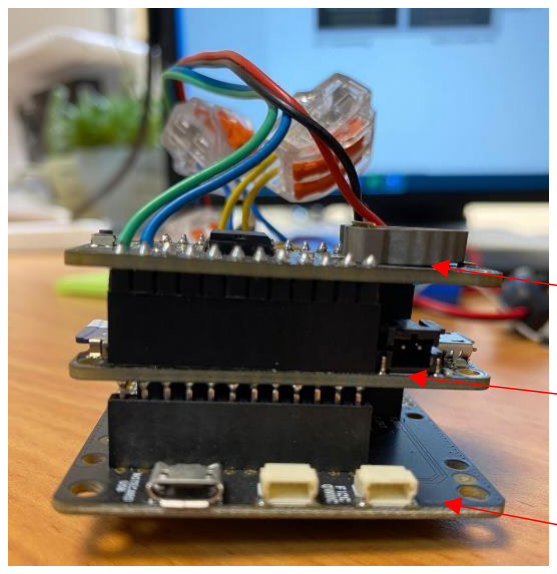
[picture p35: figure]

Soldering is needed to secure the header kit to Adalogger Feather M0 and RTC FeatherWing.

Step 3: Communicate Adalogger + Blues modem

Blues modem

Adalogger

RTC FeatherWing

- The communication between Blues modem and Adalogger can be I2C or Serial (Serial is suitable when there are a lot of sensors with long cables). Only for Serial communication, the following ports need to be connected.

On the Blues Notecarrier:

Connect F_TX → N_RX (with F stands for Feather and N stands for Notecard)

Connect F_RX → N_TX

- For power saving, the Blues modem can turn Adalogger on and off at the desired intervals.
For this function, connect F_EN → ATTN
- Put switches at the back of the Notecarrier as follows:

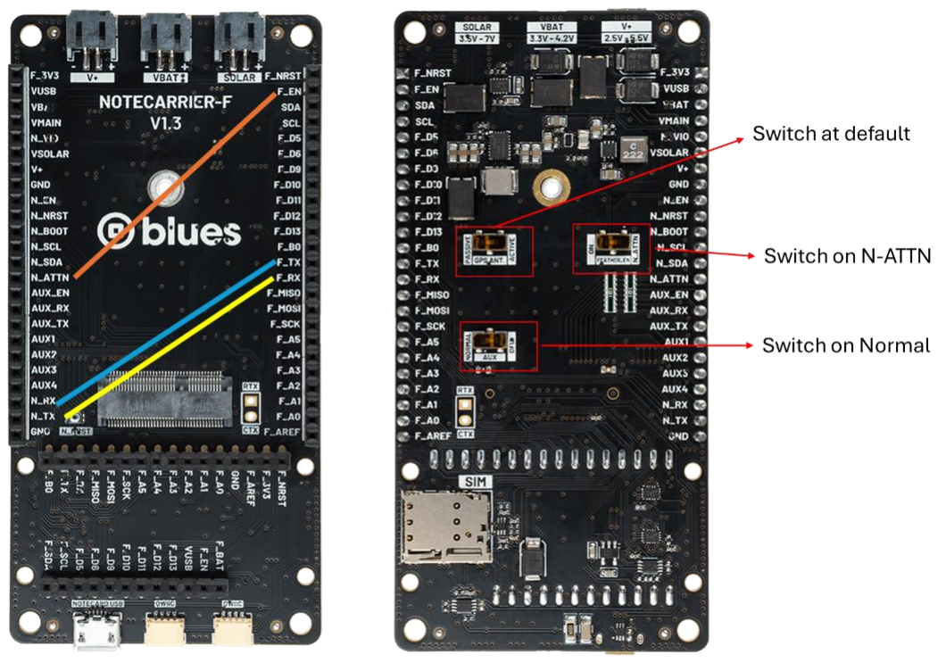
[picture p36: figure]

Step 4: Connecting the control unit to the sensor unit using a multiplexer

Plug in the Dupont connector to the matching build-in port on the multiplexer

Connect multiplexer to Adalogger feather M0 using an ST PH 4-Pin male connector:

- Solder the black wire to GND
- Solder the red wire to 3V
- Solder the blue wire to SCL
- Solder the green wire to SDA

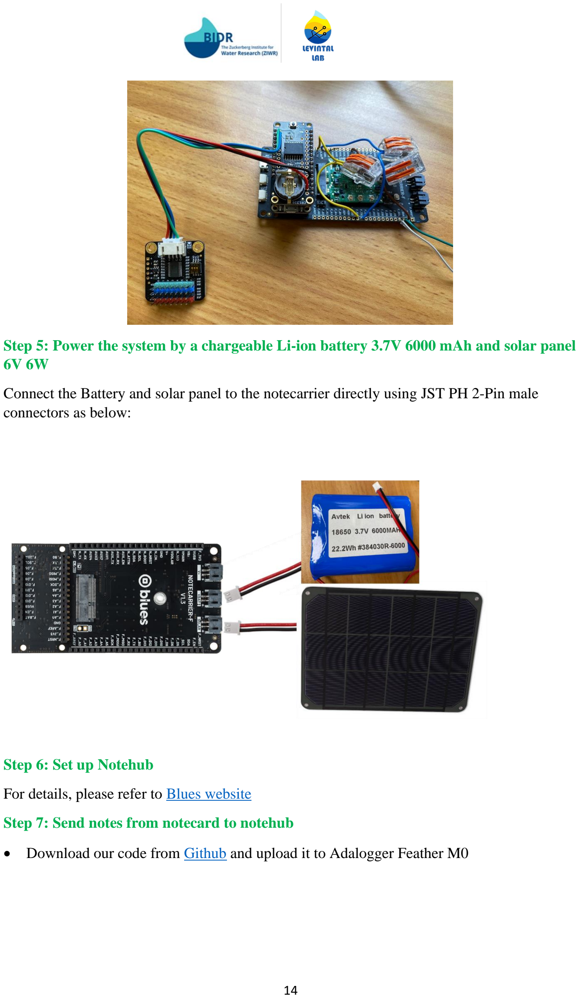
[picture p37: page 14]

Step 5: Power the system by a chargeable Li-ion battery 3.7V 6000 mAh and solar panel 6V 6W

Connect the Battery and solar panel to the notecarrier directly using JST PH 2-Pin male connectors as below:

Step 6: Set up Notehub

For details, please refer to Blues website (https://dev.blues.io/quickstart/notecard-quickstart/notecard-and-notecarrier-f/#set-up-notehub)

Step 7: Send notes from notecard to notehub
- Download our code from Github (https://github.com/OpenDigiEnvLab/soil-CO2-sensor-system) and upload it to Adalogger Feather M0

- Go to https://notehub.io/projects and see in your project if your device is connected. Below is an example of one device with dev:860264050706622 connected.


## Procedure (3): Thin coating design for waterproofing SCD30 sensor

To follow, notice that we address each side of the SCD30 sensor as follows:

Epoxy-filled side | Sensor-port side
Step 1: Connect male header pins to the SCD30 sensor.
- Cut and insert 4 male 90° header pins (https://www.mouser.co.il/ProductDetail/TE-Connectivity/3-826631-6?qs=6Tj7fpyCzVrWp9TSRmZtQw%3D%3D) into VIN, GND, SCL and SDA ports.
- Level the pin head on the sensor-port side to avoid potential damages of the filter from the protruded headers (Tips: put the sensor-port side on a flat surface and push down the pins’ black plastic dividers using a flat-head screwdriver, see pics)

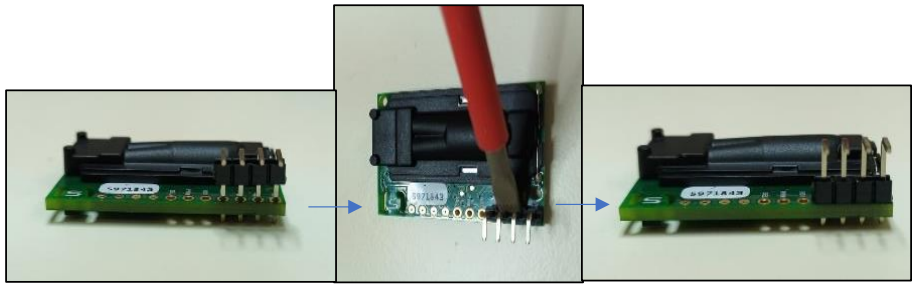
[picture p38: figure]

Step 2: Connecting SCD30 sensor with an extended cable through the male headers.
- Cut a 3m-long, 4-wire cable, expose 5cm of the cable insulators at both ends, and then expose 3-4 mm of the 4 wires’ insulators, coat wire tips with tin.

One end will be used to connect the sensor to the control unit:

- Solder 4 wires from this end to Dupont connectors (compatible to plug in the multiplexer later on)

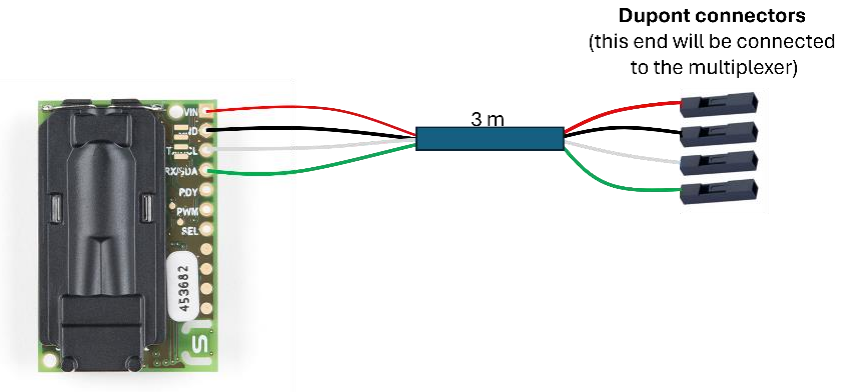
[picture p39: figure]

At the other end:

- Put a large shrinking sleeve (that fits over the cable) and 4 small shrinking sleeves over each of the 4 wires.
* Make sure that the length of the large sleeve fits from the wires’ edge and ~1cm over the cable insulation, while the small sleeves’ fits over the wires’ insulation and ~3mm more (to fit over the 90° header pins after soldering).
- Solder the wires to the 90° header pin: Red wire to ‘VIN’ port
Black wire to 'GND' port
Blue to 'SCL' port
Green wire to 'SDA' port.

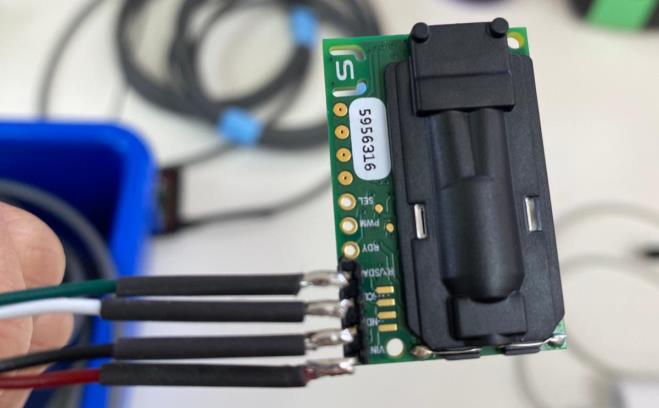
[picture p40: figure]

- Thread each of the shrinking sleeves as far down the 90° header pins as possible and shrink them using a blower, then put the large sleeve over the cable insulation and the pins and shrink it in the same way.
- Take the other end of the cable and expose ~6cm of the cable insulation, then ~3mm of each of the 4 wires’ insulation and coat the exposed wires with tin.
- Check the sensor using procedure (6).
Step 3: Plasti Dip (https://plastidip.com/product/plastidip/) sealing
- The purpose of this Plasti Dip (https://plastidip.com/product/plastidip/) sealing step is to avoid epoxy block , T- RH ports and damaging the sensor.
- Fit the SCD30 sensor into the 3D printed frame.
- Identify all the openings on the epoxy-filled side that need to be sealed (marked in red).

- Stabilize the sensor-frame unit with the epoxy-filled side face up and use a 10cc syringe and a18G needle (1.2x38mm) to slowly and carefully apply Plasti Dip on all the red marked (including the gap between the sensor and the frame, the unused round pin ports, the ports (topside only!), 2 ‘L’ shape openings on both sides of the ‘S’ logo and the 2 holes for griping with spacers).
- After drying (~30 mins) make sure no bubbles, shafts or crevasses formed due to the shrinking and drying of the Plasti Dip. If you notice any – seal individually again with Plasti Dip, wait for drying and make sure there are no holes again till it’s sealed.
- Turn the sensor-frame unit with the sensor-port face up, and seal the openings on this side as well (See picture below).

- Check the sensor using procedure (6).
Step 4: Epoxy sealing

This step is optional. Instead of epoxy sealing, users can use two PTFE membranes on two sides of the SCD30 sensors (repeat Step 5 on both sides of the sensor)

- Prepare your working environment: put paper towels on a flat, steady surface, stabilize your sensor-frame units in such a way that they’re leveled (so epoxy could be filled to the top of the frame without spilling), use latex gloves while working with epoxy.
- Prepare the mixture: We used a local manufacturer - Polymer|G (https://www.polymer-g.com/) , mixing the two components EPC 1455: EP 169 in a ratio of 1:5 (can be replaced with any locally available products).
- Weigh 2 gr of EPC 1455 and 10 gr of EP 169 and mix well for at least 2 mins (total 12 gr epoxy should be more than enough for 2 sensor-frame units – working with smaller amount is not recommended).
- Level the sensor-frame unit with the epoxy-filled side face up, pour the liquid epoxy into the frame, on top of the sensor till it reaches the top of the frame without spilling or touching anything else (e.g., your units’ stabilizing setup).

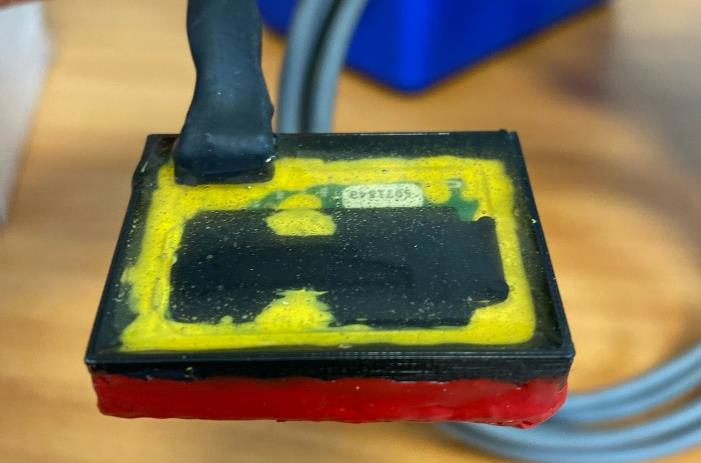
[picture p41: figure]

- Wait for it to dry between ½ day and 1.5 days (depending on the environment in which it dries).
- Check the sensor using procedure (6).
- PTFE membrane will be glued to the sensor-port side of the sensor.
- PTFE membrane used in this study is 1/16” x 6” x 6” GR Sheets from McMaster (https://www.mcmaster.com/ptfe/ultra-chemical-resistant-compressible-ptfe-gasket-material-7/) (95665K92 - 1/16'' thick), which should be cut to match the size of the 3D frame.
- Carefully apply superglue around the frame edges (see pic) and put the cut PTFE on it.
- Apply some pressure by putting a small weight on the PTFE membrane (see pic), then wait ~20 mins for drying.

- After drying, add one more layer of PlastiDip around the edges between the PTEE membrane and the frame.
- Check the sensor using procedure (6).

Superglue spread along the bottom for PTFE application

## Procedure (4): Falcon tube design for waterproofing SCD30 sensor

Step 1: Prepare the Falcon tube.
- Measure and cut the falcon tube to have a part 6cm long from the cap.
- Drill a hole big enough to pull the 4-wire cable through.
- At the cut end of the tube, cover it with PTFE membrane using superglue (the same membrane as described in the TC design) and seal the edges with PlastiDip (repeat 2 times if needed).
Step 2: Preparing SCD30 sensor.


- Use a 4-wire cable 3 m long, expose 10 cm of the cable insulator at both ends, then expose 3-4 mm of the wire insulator and coat exposed wire tips with tin.
- First end of the 3m cable: Solder 4 small wires in colors: green, white, red, and black to the corresponding ports on the sensor (SCD30) in order:
Green wire to SDA port
White wire to SCL port
Red wire to VIN port
Black wire to GND port
- Pull the cable through the hole on the Falcon tube's cap so that at the end, the SCD30 sensor will be inside the tube.

- Second end of the 3m cable: Solder 4 small wires in colors: green, white, red, black to 4-pin cable with black female Dupont connectors (see pic below):


- Seal the edges between the 4-wire cable and the hole with PlastiDip (repeat 2 times if needed).
- Put the sensor inside the tube, close the cap and complete waterproofing SCD30 sensor with Falcon tube design.


## Procedure (5): Connecting the sensor unit to the control unit version 1 and test the system


Step 1: Connect the latching relay to the multiplexer.
- Solder the white wire from the SCL port of the relay to port C in the multiplexer.
- Solder the green wire from the SCD port of the relay to port D in the multiplexer.
- Solder the black wire from the GND port of the relay to port ' – ' in the multiplexer.
Step 2: Battery unit
- Connect the solar panel to the 1.5A USB solar Lipo charger.
- Connect the Li-ion battery to the 1.5A USB solar Lipo charger at "Lipo Batt" port.
- Connect the latching relay-Adalogger unit using the read-made female port on the Adalogger to the 1.5A USB solar Lipo charger at "Load out" port.
Step 3: The multiplexer
- Connect the RTC to the multiplexer using a ready-made female port (see pic)
- Connect the green, blue, black wires of the OLED to port#0 of the multiplexer.
- Connect the green, blue, black wires of the MS8607 sensor to port#1 of the multiplexer.
- Connect the green, blue, black wires of the SCD30 to port #2-7 of the multiplexer.
Step 4: connecting red wires to control power through the latching relay.

Wire connector #1 contains:

- One of the red wires from the 'small latching piece' of the relay.
- Red wire from 3v port of the latching relay.


- Red wire from '+' port of the multiplexer.

Wire connector #2 contains:

- The other red wire from the 'small latching piece' of the relay.
- Red wire from the OLED.
- Red wire from MS8607 sensor.
- All the red wires from SCD30 sensors.

Final picture:

Step 5: Upload the Arduino code file and test the system

The procedure to upload the code file is similar to procedure (6)

## Procedure (6): Embedding Arduino code and checking sensors

First Timer (internet required):

To make sure that the shielding didn’t damage the sensors, you can check them before and after they’re sealed. The following stages are for new users and describe how to connect a PC to an SCD30 using Arduino IDE software to check the sensors:

- Use a logger setup to connect to the sensor, e.g., Feather M0 adalogger (https://learn.adafruit.com/adafruit-feather-m0-adalogger/overview) and a corresponding terminal block FeatherWing (https://www.adafruit.com/product/2926) with wires and connectors as needed (See pic on the right), and connect to a PC.


- On a PC open Arduino IDE.
- Select port and board.
- Install SparkFun SCD30 Arduino library. (https://www.arduino.cc/reference/en/libraries/sparkfun-scd30-arduino-library/)
- Upload SCD30 example code: File/Examples/Examples from Custom Libraries/Example1_BasicReadings.
- Press the Verify key and install any boards/libraries that you don’t yet have. Every time you install one, Verify again (compiles the code) and you’ll encounter another missing board/library (till no error pops up).

Second Timer

- Connect the SCD30 to the datalogger and the datalogger to a PC (See ‘First Timer’ section).
- Open Arduino IDE
- Send example code to datalogger by pressing the Upload key.
- Open ‘Serial Monitor’ and make sure that all values make sense (Temp, RH and ). Blow on the sensor to watch the values change accordingly.

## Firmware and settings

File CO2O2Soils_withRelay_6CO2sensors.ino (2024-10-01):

/*

Adalogger, Relay latching, RTC (DS3231) (0x68), TCA9548A(I2C Multiplexer)(0x70), Monochrome 0.96" 128x64 OLED Graphic Display - STEMMA QT(0x3D)
TCA9548A(I2C Multiplexer): 
Address0->MS8607(0x76)
Address1->Monochrome 0.96" 128x64 OLED Graphic Display - STEMMA QT(0x3D)
Address2->SCD30A (0x61)
Address3->SCD30B (0x61)
Address4->SCD30C (0x61)
Address5->SCD30D (0x61)
Address6->SCD30E (0x61)
Address7->SCD30F (0x61)
BASED ON THE CODE FROM THE FORUM "https://forums.adafruit.com/viewtopic.php?f=25&t=138929", an excellent example how to connect two (or more) different sensors on one multiplexer (if I understand it correctly)
2*KE25 (O2 sensors) connected to the ADS1115 (KE2A to A0-A1, KE25B to A2-A3)
*/

#define TCAADDR 0x70
#include "Wire.h"
// extern "C" {
// #include "utility/twi.h"  // from Wire library, so we can do bus scanning 
// }
#include <Wire.h>
#include <SPI.h>
#include "RTClib.h" // the I2C address is 0x68. For the real time clock commands, please read the LICENSE and README files before downloading the library at https://github.com/adafruit/RTClib
#include <SD.h>
#include <Adafruit_GFX.h>//OLED
#include <Adafruit_SSD1306.h>//OLED
#include <Adafruit_SleepyDog.h> // for sleep mode between readings, please read the LICENSE and README files before downloading the library at https://github.com/adafruit/Adafruit_SleepyDog
#include <Arduino.h>
#include "SparkFun_SCD30_Arduino_Library.h" //Click here to get the library: http://librarymanager/All#SparkFun_SCD30
#include <Adafruit_Sensor.h>
#include <Adafruit_ADS1X15.h>
#include <Adafruit_MS8607.h>

int Interval=10;// [min] logging interval
int i = 0;//flag to make sure tat the it will not go into sleep mode during the first time after setup
int SLEEP_TIME = 9*60; // //go into sleep mode for..[seconds]
int cycleIndex=1;
int MinutesPerDay = 1440;

//RTC//
char buffer [24];
uint8_t secq, minq, hourq, dayq, monthq, yearq ;
RTC_DS3231 rtc;
//RTC_DS1307 rtc;
float rtcT; 
////


//SD card//
char FileName[]="26032023.txt";// change the file name
// char FileName[]="26032023.csv";// change the file name
const int chipSelect = 4;//SD input
//String LoggerHeader = "Date [hh:mm:ss dd/mm/yyyy],CO2 [ppm] (K30), CO2 [ppm] (SCD30),T [C] (SCD30),RH [%] (
String LoggerHeader = "CO2O2Soils_Mashas1";//insert the heaters for the SD logging
// #define LED 8 // to be used as datalogging indicator
////

//Power relay (latching type)///
int RelayPinOn = 13;//SET in relay connected to pin#13
int RelayPinOff = 12;//UNSET in relay connected to pin#12
////

//Measuring battery voltage///
#define VBATPIN A7
float measuredvbat = 0;
////

////128x64 OLED////
#define SCREEN_WIDTH 128 // OLED display width, in pixels
#define SCREEN_HEIGHT 64 // OLED display height, in pixels
// Declaration for an SSD1306 display connected to I2C (SDA, SCL pins)
// The pins for I2C are defined by the Wire-library. 
// On an arduino UNO:       A4(SDA), A5(SCL)
// On an arduino MEGA 2560: 20(SDA), 21(SCL)
// On an arduino LEONARDO:   2(SDA),  3(SCL), ...
#define OLED_RESET     -1 // Reset pin # (or -1 if sharing Arduino reset pin)
#define SCREEN_ADDRESS 0x3D ///< See datasheet for Address; 0x3D for 128x64, 0x3C for 128x32
Adafruit_SSD1306 display(SCREEN_WIDTH, SCREEN_HEIGHT, &Wire, OLED_RESET);
////////

//ADS1115//
Adafruit_ADS1115 ads1115;//
float bitValue2 = 0.0078125;// how much 1 bit equals
float O2A = 0;
float O2B = 0;
float O2A_percentage = 0;
float O2B_percentage = 0;
////

//SCD30 section
SCD30 airSensor; //The SCD30 has data ready every two seconds
int CO2SCD30A = 0;
float TemperatureSCD30A = 0;
float RHSCD30A = 0;
int CO2SCD30B = 0;
float TemperatureSCD30B = 0;
float RHSCD30B = 0;
int CO2SCD30C = 0;
float TemperatureSCD30C = 0;
float RHSCD30C = 0;
int CO2SCD30D = 0;
float TemperatureSCD30D = 0;
float RHSCD30D = 0;
int CO2SCD30E = 0;
float TemperatureSCD30E = 0;
float RHSCD30E = 0;
int CO2SCD30F = 0;
float TemperatureSCD30F = 0;
float RHSCD30F = 0;
////



//MS8607//
Adafruit_MS8607 ms8607;
double ms8607T = 0;//[C]
double ms8607P = 0;//[hPa]
double ms8607RH = 0;//[%]
////


void setup() {
  Serial.begin(9600);
    // delay(100);//Some of the sensors need a few seconds between power on with the relay and taking a reading or initiating the SD


  pinMode(RelayPinOn, OUTPUT);// initialize digital pin 13 as an output.
  pinMode(RelayPinOff, OUTPUT);// initialize digital pin 12 as an output.
    
    Serial.println("Test1 ");

  digitalWrite(RelayPinOn,HIGH);   // turn the LED on (HIGH is the voltage level)
  delay(200);//pulse each pin high for 10ms to latch the relay open or closed. 
  digitalWrite(RelayPinOn, LOW);   // turn the LED on (HIGH is the voltage level)
  delay(4000);//Some of the sensors need a few seconds between power on with the relay and taking a reading or initiating the SD
  Serial.println("Test2 ");

  
  //RTC//
  #ifndef ESP8266
    //while (!Serial); // wait for serial port to connect. Needed for native USB
  #endif

  if (! rtc.begin()) {
    rtc.adjust(DateTime(F(__DATE__), F(__TIME__)));

    Serial.println(F("Couldn't find RTC"));
    Serial.flush();
    // abort();
  }
    Serial.println("Test3 ");

//Calibraet the rtc acording to UTC+2 (winter time in Israel)//
// rtc.adjust(DateTime(F(__DATE__), F(__TIME__))); // USE ONLY IF WINTER TIME IS SET IN THE CONNECTED COMPUTER
// rtc.adjust(DateTime(F(__DATE__), F(__TIME__))- TimeSpan(0,1,0,0)); // USE ONLY IF SUMMER TIME IS SET IN THE CONNECTED COMPUTER (*)e.g., minus 1 hour)
 ////

 //SD card//
 delay(10);
 Serial.print(F("Initializing SD card..."));
 // see if the card is present and can be initialized:
 SD.begin(chipSelect);
 if (!SD.begin(chipSelect)) {
   Serial.println(F("Card failed, or not present"));
  // don't do anything more:
  // while (1);
  }
  Serial.println(F("card initialized."));
  Serial.print("File name: ");
  Serial.print(FileName);
  File dataFile = SD.open(FileName, FILE_WRITE);// testing if this is a new file then add heaters
  Serial.print("File size: ");
  Serial.println(dataFile.size());
  if (dataFile.size()==0){
    dataFile.println(LoggerHeader);
    // print to the serial port too:
    Serial.println(LoggerHeader);
  }
  dataFile.close();
  delay(10);
 ////

 //ADS1115//
  // The ADC input range (or gain) can be changed via the following
  // functions, but be careful never to exceed VDD +0.3V max, or to
  // exceed the upper and lower limits if you adjust the input range!
  // Setting these values incorrectly may destroy your ADC!
  //                                                                ADS1015  ADS1115
  //                                                                -------  -------
  // ads.setGain(GAIN_TWOTHIRDS);  // 2/3x gain +/- 6.144V  1 bit = 3mV      0.1875mV (default)
  // ads.setGain(GAIN_ONE);        // 1x gain   +/- 4.096V  1 bit = 2mV      0.125mV
  // ads.setGain(GAIN_TWO);        // 2x gain   +/- 2.048V  1 bit = 1mV      0.0625mV
  // ads.setGain(GAIN_FOUR);       // 4x gain   +/- 1.024V  1 bit = 0.5mV    0.03125mV
  // ads.setGain(GAIN_EIGHT);      // 8x gain   +/- 0.512V  1 bit = 0.25mV   0.015625mV
  // ads.setGain(GAIN_SIXTEEN);    // 16x gain  +/- 0.256V  1 bit = 0.125mV  0.0078125mV

  // tcaselect(1);
  ads1115.begin();// Construct an ads1015 at the default
  ads1115.setGain(GAIN_SIXTEEN); // 16x gain  +/- 0.256V  1 bit = 0.0078125mV
   ////
    // Serial.println("Test3a ");







  digitalWrite(RelayPinOff,HIGH);   // turn the LED on (HIGH is the voltage level)
  delay(20);//pulse each pin high for 10ms to latch the relay open or closed. 
  digitalWrite(RelayPinOff, LOW);   // turn the LED on (HIGH is the voltage level)
  
}

void loop() {

// delay(1*60*1000);




int loopTimeSec = round(22660*0.001);//[sec] this is the duration of the sensors and datalogging loop - SHOULD BE CAHNGED IF THE CODE IS CHANGED
//instead of sleep mode//
if (i==1){ 
// delay((Interval-1)*60*1000);
delay(((Interval-1)*60*1000)+((loopTimeSec*1000)-5000));

// delay((Interval-(loopTimeSec*1000)-5000)*60*1000);

i = 0;
}

////
    //go into sleep mode//

  // if (i==1){   
  //   for(int q= 0; q < SLEEP_TIME / 8; q++) { // this section was adjusted from "https://tum-gis-sensor-nodes.readthedocs.io/en/latest/adafruit_32u4_lora/README.html"
  //     Watchdog.sleep(8000); // in milliseconds - the watchdog timer max sleep time is 8 seconds so an adjustment is needed (see the link above for additional details)
  //   }
  //   if (SLEEP_TIME % 8) {
  //     Watchdog.sleep((SLEEP_TIME % 8)*1000);
  //    }
  //   //  delay (9000-33.333);//add this to the SLEEP_TIME to set interval
  //   i=0;
  // }

//delay (5000-33.333);  
  //////////////////////

  int StartOfLoop = millis();
  Serial.print("start of ?-min interval loop in milis:");
  Serial.println(StartOfLoop);
      
      Serial.println("Relay pin on start");       
  digitalWrite(RelayPinOn,HIGH);   // turn the LED on (HIGH is the voltage level)
  delay(20);//pulse each pin high for 10ms to latch the relay open or closed. 
  digitalWrite(RelayPinOn, LOW);   // turn the LED on (HIGH is the voltage level)
  Serial.println("Relay pin on end"); 
  //sensor warm up time should be ~10 sec from relay on to first CO2 measurement


   //RTC//
  // rtc.begin(); // this line should be uncomment only if using the relay
  rtcT = rtc.getTemperature();
  DateTime now = rtc.now();
  secq = now.second();
  minq = now.minute();
  hourq = now.hour();
  dayq = now.day();
 monthq = now.month(); 
  sprintf (buffer, "%02u:%02u:%02u %02u/%02u", hourq, minq, secq, dayq, monthq);//this is to zero in single nreadings (e.g., 5 sec to 05 sec)
  

  Serial.print ("Minutes:");
  Serial.print (minq);
  Serial.print (" Seconds:");
  Serial.println (secq);

  // if(display.begin(SSD1306_SWITCHCAPVCC, SCREEN_ADDRESS)) {
  //     display.clearDisplay();
  //     display.setTextSize(1);
  //     display.setTextColor(WHITE);
  //     display.setCursor(0,0);
  //     display.print("");
  //     display.print("Second:");display.print(secq);display.print("minutes");display.print(minq);
  //     display.display();     

  //    }//part of the OLED

  int Mod_A = (hourq*60+minq) % Interval ;
  if (Mod_A == 0 && secq == 0){//Comment if ?-min interval is not needed
    int countdownMS = Watchdog.enable(60000); // start a 60 seconds timer - this will reset the microcontroller in case it will get stuck in the loop (e.g., a problematic sensor)




     //ADS1115//
    O2A = ads1115.readADC_Differential_0_1()*bitValue2;//[mV]
    O2B = ads1115.readADC_Differential_2_3()*bitValue2;//[mV]
    O2A_percentage = 1.79031686955191*O2A-0.427551020408163;//[%]
    O2B_percentage = 1.74752514028074*O2B-0.427551020408163;//[%]
    ////

      //Measuring battery voltage///
    measuredvbat = analogRead(VBATPIN);
    measuredvbat *= 2;    // we divided by 2, so multiply back
    measuredvbat *= 3.3;  // Multiply by 3.3V, our reference voltage
    measuredvbat /= 1024; // convert to voltage
    ////

  //SCD30 section - start//
    tcaselect(2);
    if (airSensor.begin()){;// this line should be uncomment only if using the relay
    delay(100);
    if (airSensor.dataAvailable())
    {
      CO2SCD30A = airSensor.getCO2();
      TemperatureSCD30A = airSensor.getTemperature(), 1;
      RHSCD30A = airSensor.getHumidity(), 1;
      // Serial.println(TemperatureSCD30A10cm);
      Serial.println("CO2_A-V ");

    }
          // Serial.println("Test5: ");
    }
    tcaselect(3);
    if (airSensor.begin()){;// this line should be uncomment only if using the relay
    delay(100);
      if (airSensor.dataAvailable())
    {
      CO2SCD30B = airSensor.getCO2();
      TemperatureSCD30B = airSensor.getTemperature(), 1;
      RHSCD30B = airSensor.getHumidity(), 1;
      // Serial.println(TemperatureSCD30B10cm);
      Serial.println("CO2_B-V ");

    }
    }

        tcaselect(4);
    if (airSensor.begin()){;// this line should be uncomment only if using the relay
    delay(100);
      if (airSensor.dataAvailable())
    {
      CO2SCD30C = airSensor.getCO2();
      TemperatureSCD30C = airSensor.getTemperature(), 1;
      RHSCD30C = airSensor.getHumidity(), 1;
      // Serial.println(TemperatureSCD30B10cm);
      Serial.println("CO2_C-V ");

    }
    }

        tcaselect(5);
    if (airSensor.begin()){;// this line should be uncomment only if using the relay
    delay(100);
      if (airSensor.dataAvailable())
    {
      CO2SCD30D = airSensor.getCO2();
      TemperatureSCD30D = airSensor.getTemperature(), 1;
      RHSCD30D = airSensor.getHumidity(), 1;
      // Serial.println(TemperatureSCD30B10cm);
      Serial.println("CO2_D-V ");

    }
    }

        tcaselect(6);
    if (airSensor.begin()){;// this line should be uncomment only if using the relay
    delay(100);
      if (airSensor.dataAvailable())
    {
      CO2SCD30E = airSensor.getCO2();
      TemperatureSCD30E = airSensor.getTemperature(), 1;
      RHSCD30E = airSensor.getHumidity(), 1;
      // Serial.println(TemperatureSCD30B10cm);
      Serial.println("CO2_E-V ");

    }
    }

        tcaselect(7);
    if (airSensor.begin()){;// this line should be uncomment only if using the relay
    delay(100);
      if (airSensor.dataAvailable())
    {
      CO2SCD30F = airSensor.getCO2();
      TemperatureSCD30F = airSensor.getTemperature(), 1;
      RHSCD30F = airSensor.getHumidity(), 1;
      // Serial.println(TemperatureSCD30B10cm);
      Serial.println("CO2_F-V ");

    }
    }

 //SCD30 section - end//
    
      //MS8607//
    tcaselect(0);
    if (ms8607.begin()) {
      delay(100);

    //setup lines - these lines are here due to the use of the relay
    ms8607.setHumidityResolution(MS8607_HUMIDITY_RESOLUTION_OSR_8b);
    switch (ms8607.getHumidityResolution()){
    // case MS8607_HUMIDITY_RESOLUTION_OSR_12b: Serial.println("12-bit"); break;
    // case MS8607_HUMIDITY_RESOLUTION_OSR_11b: Serial.println("11-bit"); break;
    // case MS8607_HUMIDITY_RESOLUTION_OSR_10b: Serial.println("10-bit"); break;
    // case MS8607_HUMIDITY_RESOLUTION_OSR_8b:  Serial.println("8-bit"); break;
  }
  // ms8607.setPressureResolution(MS8607_PRESSURE_RESOLUTION_OSR_4096);
  //Serial.print("Pressure and Temperature resolution set to ");
  switch (ms8607.getPressureResolution()){
    // case MS8607_PRESSURE_RESOLUTION_OSR_256: Serial.println("256"); break;
    // case MS8607_PRESSURE_RESOLUTION_OSR_512: Serial.println("512"); break;
    // case MS8607_PRESSURE_RESOLUTION_OSR_1024: Serial.println("1024"); break;
    // case MS8607_PRESSURE_RESOLUTION_OSR_2048: Serial.println("2048"); break;
    // case MS8607_PRESSURE_RESOLUTION_OSR_4096: Serial.println("4096"); break;
    // case MS8607_PRESSURE_RESOLUTION_OSR_8192: Serial.println("8192"); break;
  }
  ////end of setup lines
      sensors_event_t temp, pressure, humidity;
      ms8607.getEvent(&pressure, &temp, &humidity);
      ms8607T = temp.temperature;//[C]
      ms8607P = pressure.pressure;//[hPa]
      ms8607RH = humidity.relative_humidity;//[%]
    }
    Serial.println("Sensor ms8607T - V");
    ////

  
    //SD logging//
    // make a string for assembling the data to log:
    String dataString = ""; 
    dataString += String(buffer);dataString += "/";dataString += String(now.year());  //HH:MM:SS DD/MM/YY
      String timeString = ""; 
      timeString += dataString;
    dataString += ",";
    dataString += String(CO2SCD30A);
    dataString += ",";
    dataString += String(TemperatureSCD30A);
    dataString += ",";
    dataString += String(RHSCD30A);
    dataString += ",";
    dataString += String(CO2SCD30B);
    dataString += ",";
    dataString += String(TemperatureSCD30B);
    dataString += ",";
    dataString += String(RHSCD30B);
        dataString += ",";
    dataString += String(CO2SCD30C);
    dataString += ",";
    dataString += String(TemperatureSCD30C);
    dataString += ",";
    dataString += String(RHSCD30C);
        dataString += ",";
    dataString += String(CO2SCD30D);
    dataString += ",";
    dataString += String(TemperatureSCD30D);
    dataString += ",";
    dataString += String(RHSCD30D);
        dataString += ",";
    dataString += String(CO2SCD30E);
    dataString += ",";
    dataString += String(TemperatureSCD30E);
    dataString += ",";
    dataString += String(RHSCD30E);
        dataString += ",";
    dataString += String(CO2SCD30F);
    dataString += ",";
    dataString += String(TemperatureSCD30F);
    dataString += ",";
    dataString += String(RHSCD30F);
        dataString += ",";        
    dataString += String(O2A);
    dataString += ",";   
    dataString += String(O2B);
    dataString += ",";
    dataString += String(O2A_percentage);
    dataString += ",";
    dataString += String(O2B_percentage);
    dataString += ",";       
    dataString += String(ms8607T);
    dataString += ",";
    dataString += String(ms8607P);
    dataString += ",";
    dataString += String(ms8607RH);
    dataString += ",";
    dataString += String(measuredvbat);//[V]
    dataString += ",";
    dataString += String(cycleIndex);//how many sensors measurement cycles were conducted from the last reset
    



    // open the file. note that only one file can be open at a time,
    // so you have to close this one before opening another.
    // digitalWrite(LED, HIGH);
    delay(500);
    File dataFile = SD.open(FileName, FILE_WRITE);
    delay(500);
    // if the file is available, write to it:
    if (dataFile) {
      dataFile.println(dataString);
      dataFile.close();
      // print to the serial port too:
      Serial.println(dataString);
       ////128x64 OLED////
       tcaselect(1);
       delay(100);
      if(display.begin(SSD1306_SWITCHCAPVCC, SCREEN_ADDRESS)) {
          display.clearDisplay();
          display.setTextSize(1);
          display.setTextColor(WHITE);
          display.setCursor(0,0);
          display.print(dataString);
          // display.println(timeString);
          // display.print("CO2:");display.print(CO2SCD30A);display.print(",");display.print(CO2SCD30B);display.print(",");display.print(CO2SCD41C);display.print(",");display.print(CO2SCD41D);display.print(";");
          // display.print("O2:");display.print(O2A_percentage);display.print(",");display.print(O2B_percentage);display.print(";");
          // display.print("B[V]:");display.print(measuredvbat);display.print(";");
          display.display();
          // delay(5000); 
      }//part of the OLED

    // digitalWrite(LED, LOW);  
    }
       // if the file isn't open, pop up an error:
    else {
      Serial.println(F("error opening datalog file"));

      ////128x64 OLED////
      tcaselect(1);
      delay(50);

  if(display.begin(SSD1306_SWITCHCAPVCC, SCREEN_ADDRESS)) {
      display.clearDisplay();
      display.setTextSize(1);
      display.setTextColor(WHITE);
      display.setCursor(0,0);
      display.println(timeString);
      display.print("NO SD!");
      display.print(dataString);
      display.display();

     }//part of the OLED
      Watchdog.enable(5*1000);//reset the adalogger after 5sec if no SD wad logged
      delay(7*1000); 
      
    }
    
    delay(10000);
    digitalWrite(RelayPinOff,HIGH);   // turn the LED on (HIGH is the voltage level)
    delay(20);//pulse each pin high for 10ms to latch the relay open or closed. 
    digitalWrite(RelayPinOff, LOW);   // turn the LED on (HIGH is the voltage level)

  //Reset the device once a day//
  cycleIndex++;
  if (cycleIndex> (MinutesPerDay/Interval)){
      Serial.println("testReset");
      cycleIndex=1;
      Watchdog.enable(1000);// reset the device
      delay(2000);
  } 
  ////



  Watchdog.disable(); // end the 60 seconds timer

  i=1;
  } //end of 1-min interval
  int EndOfLoop = millis();
  Serial.print("end of ?-min interval loop in millis:");
  Serial.println(EndOfLoop);
  Serial.print("Toal ?-min interval loop in millis:");
  Serial.println(EndOfLoop-StartOfLoop); 
  Serial.println("----------------------------------------------------------------------");

  // delay(3000);

}


void tcaselect(uint8_t i) {
  if (i > 7) return;

  Wire.beginTransmission(TCAADDR);
  Wire.write(1 << i);
  Wire.endTransmission();
}

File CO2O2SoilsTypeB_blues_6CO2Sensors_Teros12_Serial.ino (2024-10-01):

//Soil CO2 sensor system includes:
//Notecard Cellular + Notecarrier F        Serial1
//Feather M0 adalogger with SD card
//RTC DS3231 featherwing                  (I2C - 0x68)
//Multiplexer TCA9548A  (DFrobot)         (I2C - 0x70)
// 6 CO2 sensors (on mux ports 0-5)
// 1 microclimate sensors MS8607 (on mux port: 6)
//1 soil moisture sensor TDR teros12
//Li ion battery 3.7 volt 
//Solar panel 6V 6W


// notecard and hub:       using sleepy sensor example, the feather samples every fixed interval (that can be changed in notehub) 
//                         and sends data to notehub depending on the system voltage
//                         In order to allow the notecarrier to do this the Notecard's `ATTN`* pin is wired to the enable pin 'EN' of the adalogger
//                         Sync to notehub every reading

//Import libraries
#include <Wire.h>  //include arduinos i2c library
#include <SPI.h>
#include <SD.h>
#include <RTClib.h>
#include <Notecard.h>                        // Include the Arduino library for the Notecard
#include "SparkFun_SCD30_Arduino_Library.h"  //Click here to get the library: http://librarymanager/All#SparkFun_SCD30
#include "SDI12_ARM.h"                       //include library for the moisture sensor  GS3 https://github.com/ManuelJimenezBuendia/Arduino-SDI-12. here we use Teros 12 but we can use the same library
#include <Adafruit_MS8607.h>                 //include library for microclimate sensor MS8607


#define TCAADDR 0x70 //address of I2C mux


//define variables for 6 CO2 sensors (each include CO2 concentration, Temperature, and RH), labeled from A-F
SCD30 airSensor;           //The SCD30 has data ready every two seconds
float CO2SCD30A, TemperatureSCD30A, RHSCD30A, CO2SCD30B, TemperatureSCD30B, RHSCD30B, CO2SCD30C, TemperatureSCD30C, RHSCD30C;  //float var used to hold the values of sensors
float CO2SCD30D, TemperatureSCD30D, RHSCD30D, CO2SCD30E, TemperatureSCD30E, RHSCD30E, CO2SCD30F, TemperatureSCD30F, RHSCD30F;  //float var used to hold the values of sensors

//define variable for microlimate sensor MS8607//
Adafruit_MS8607 ms8607;
double ms8607T = 0;//[C]
double ms8607P = 0;//[hPa]
double ms8607RH = 0;//[%]

// Moisture sensor constants Teros12//
static const uint16_t pin_GS3_SDI12 = 6;  // Set the pins used on main control board (connect the sensor's data wire to port "6" or change the port and update it here)
SDI12 GS3_SDI12(pin_GS3_SDI12);           // Create an SDI-12 object and commands;
static const String myCommandInfo = "?I!"; //"?I!" = get info; // returns address and unit specs 
static const String myCommandMeas = "0M!";   //"aM!" = take measurement; 
static const String myCommandData = "0D0!";  //"aD0!" = read data; // returns "address+calibratedcountsVWC+temp+EC". To convert calibratedcountsSWC or TDR_RAW to VWC use the general equation provided in manual guide of TEROS12
char* samples;
// Teros12 values
float TDR_RAW; //this is termed calibrated counts as in the manual guide. This value is not SWC or dielectric, it has to be calibrated to convert to SWC or dielectric. The manufacturer provided an equation to convert for general minineral soil
float TDR_degC; //for soil temperature
float TDR_bulkEC; //for bulk elecetric conductivity

//logging file and SD card define. Measurement readings are sent to notehub but still SD card is used as a backup
char FileName[] = "soilCO2.txt";                     // logging file name
const int chipSelect = 4;                             // SD input - feather M0
String LoggerHeader = "Time , Date ,  Battery_Volt";  //headers- will be printed on the first line of the file


//define variable for RTC temp
float RTCtemp;
RTC_DS3231 rtc;                           //RTC define
char buffer[24];                          //float var used to hold time and date
uint8_t secq, minq, hourq, dayq, monthq;  //float var used to hold the sec, min, hour, day and month

//Battery volt
#define VBATPIN A7       //Bat pin feather
float Batt_V = 0;             //float variable for adalogger voltage
float BluesVoltage = 0;       //float variable for Notecarrier voltage

int getInterval();  // calls function that returns the reading_interval from the environment variables



//note hub define
#define productUID "il.ac.bgu.levintal:co2o2soils"  //the unique Product Identifier for your device - set at notehub
#define myProductID productUID
Notecard notecard;
//#define txRxPinsSerial Serial1                                  //uncomment when using UART protocol
#define usbSerial Serial


void setup() {
  //while (!Serial); delay(1000);           //uncomment if you want to debug with serial
  Serial.begin(115200);
  notecard.setDebugOutputStream(usbSerial);  // enables to watch JSON objects being transferred to and from the Notecard for each request on the serial terminal window
  notecard.begin(Serial1, 9600);               //uncomment when using UART protocol
  // notecard.begin();  //start notecard with I2C protocol
  Wire.begin();      //start the I2C

  // Provide visual signal when the Host MCU is powered
  ::pinMode(LED_BUILTIN, OUTPUT);
  ::digitalWrite(LED_BUILTIN, HIGH);

  Serial.println("CO2 soil system");
  Serial.println("system setup, please wait");
  delay(100);
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
